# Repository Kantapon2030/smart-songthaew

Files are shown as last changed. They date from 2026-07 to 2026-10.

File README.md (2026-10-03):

# 🚎 SMART SONGTHAEW PLATFORM
### แพลตฟอร์มสมาร์ทสองแถว: สถาปัตยกรรมคลาวด์และไอโอทีติดตามยานพาหนะแบบเรียลไทม์ เพื่อยกระดับคุณภาพชีวิตและลดความเหลื่อมล้ำทางดิจิทัลด้านการเดินทางของประชาชนในส่วนภูมิภาค


[]()
[]()
[]()
[]()
[]()

> **การแข่งขันพัฒนาโปรแกรมคอมพิวเตอร์แห่งประเทศไทย ครั้งที่ 28 (The 28th National Software Contest: NSC 2026)**  
> **หมวดการแข่งขัน:** โปรแกรมเพื่อการประยุกต์ใช้งานบนเครือข่าย หรือโปรแกรมเพื่อพัฒนาคุณภาพชีวิตและสังคม (หมวด 23)  
> **รหัสโครงการ:** `28P23S00194`  
> **ผู้พัฒนา:** นายกันตภณ วงศ์พรต (นักเรียนชั้นมัธยมศึกษาปีที่ 6)  
> **อาจารย์ที่ปรึกษา:** นายอัศวิน จุลมูล  
> **สถานศึกษา:** โรงเรียนเตรียมอุดมศึกษาภาคใต้ จังหวัดนครศรีธรรมราช  
> **ระบบทดสอบจริง (Live Production):** [https://smart-songthaew.onrender.com](https://smart-songthaew.onrender.com)

---

## 📌 สารบัญ (Table of Contents)

1. [ความเป็นมา ที่มาของปัญหา และแรงบันดาลใจ (Background & Motivation)](#1-ความเป็นมา-ที่มาของปัญหา-และแรงบันดาลใจ-background--motivation)
2. [ปัญหาที่แท้จริงของ 2 ฝ่าย (Two-Sided Pain Points)](#2-ปัญหาที่แท้จริงของ-2-ฝ่าย-two-sided-pain-points)
3. [นวัตกรรมและแนวคิดหลักของโครงการ (Core Innovations & Concepts)](#3-นวัตกรรมและแนวคิดหลักของโครงการ-core-innovations--concepts)
4. [สถาปัตยกรรมระบบโดยรวม (System Architecture)](#4-สถาปัตยกรรมระบบโดยรวม-system-architecture)
5. [การออกแบบฮาร์ดแวร์ VIBE และกล่อง 3D PETG (Hardware & Mechanical Design)](#5-การออกแบบฮาร์ดแวร์-vibe-และกล่อง-3d-petg-hardware--mechanical-design)
6. [ผลการทดสอบระบบและประสิทธิภาพภาคสนาม (Field Test & Validation Results)](#6-ผลการทดสอบระบบและประสิทธิภาพภาคสนาม-field-test--validation-results)
7. [ผลกระทบเชิงเศรษฐกิจ สังคม และความยั่งยืน (Social & Economic Impact)](#7-ผลกระทบเชิงเศรษฐกิจ-สังคม-และความยั่งยืน-social--economic-impact)
8. [คุณสมบัติของซอฟต์แวร์และส่วนติดต่อผู้ใช้ (Software Features)](#8-คุณสมบัติของซอฟต์แวร์และส่วนติดต่อผู้ใช้-software-features)
9. [คู่มือการติดตั้งและทดสอบสำหรับนักพัฒนา (Developer & Deployment Guide)](#9-คู่มือการติดตั้งและทดสอบสำหรับนักพัฒนา-developer--deployment-guide)
10. [ปัญหา อุปสรรค และแนวทางการพัฒนาต่อยอด (Challenges & Future Work)](#10-ปัญหา-อุปสรรค-และแนวทางการพัฒนาต่อยอด-challenges--future-work)
11. [ข้อมูลคณะผู้จัดทำและช่องทางติดต่อ (Credits & Contact Information)](#11-ข้อมูลคณะผู้จัดทำและช่องทางติดต่อ-credits--contact-information)

---

## 1. ความเป็นมา ที่มาของปัญหา และแรงบันดาลใจ (Background & Motivation)

### บริบทความเหลื่อมล้ำของระบบขนส่งสาธารณะไทย
ในเขตกรุงเทพมหานครและเมืองศูนย์กลางเศรษฐกิจขนาดใหญ่ เทคโนโลยีติดตามยานพาหนะสาธารณะแบบดิจิทัล (เช่น รถไฟฟ้า BTS/MRT, รถเมล์ ขสมก. ผ่าน ViaBus) ได้ช่วยให้ประชาชนสามารถตรวจสอบเส้นทาง ตำแหน่งรถแบบเรียลไทม์ และวางแผนการเดินทางในชีวิตประจำวันได้อย่างสะดวกรวดเร็ว

ทว่าใน **พื้นที่ต่างจังหวัดและส่วนภูมิภาค** รถสาธารณะหลักที่หล่อเลี้ยงวิถีชีวิตของผู้คนไม่ใช่รถไฟฟ้าหรือรถเมล์ขนาดใหญ่ แต่คือ **"รถสองแถว"** ซึ่งเป็นระบบขนส่งมวลชนท้องถิ่นที่เชื่อมโยงระหว่างบ้าน โรงเรียน ตลาด สถานที่ทำงาน โรงพยาบาล และศูนย์กลางชุมชนเข้าด้วยกัน อย่างไรก็ดี รถสองแถวในปัจจุบันยังคงเป็นระบบขนส่งแบบดั้งเดิม (Analog) ที่ **"ผู้โดยสารมองไม่เห็น"** ไม่มีระบบดิจิทัลบอกตำแหน่ง ไม่ทราบตารางเวลาที่แน่นอน และไม่มีช่องทางตรวจสอบว่ารถคันถัดไปจะมาถึงเมื่อใด

### ความสอดคล้องกับนโยบายระดับประเทศและสากล
- **ข้อเสนอเชิงนโยบาย TDRI:** สถาบันวิจัยเพื่อการพัฒนาประเทศไทย (TDRI) ระบุว่า แกนหลักของปัญหาการขนส่งสาธารณะไทยผูกอยู่กับ 3 มิติคือ **"เวลา ความแน่นอน และการเข้าถึงพื้นที่ปลายทาง"** พร้อมเสนอว่ารถโดยสารสาธารณะที่ได้รับการยกระดับควรติดตั้งระบบ GPS และเชื่อมต่อแอปพลิเคชันให้ผู้โดยสารตรวจสอบตำแหน่งได้จริง
- **เป้าหมายการพัฒนาที่ยั่งยืน (UN SDG 11.2):** โครงการนี้มุ่งสนับสนุนเป้าหมาย SDG 11 (Sustainable Cities and Communities) ข้อ 11.2 ว่าด้วยการจัดให้ทุกคนสามารถเข้าถึงระบบคมนาคมขนส่งที่ปลอดภัย ราคาย่อมเยา เข้าถึงได้สะดวก และยั่งยืน เพื่อลดความเหลื่อมล้ำทางดิจิทัล (Digital Divide) ด้านการเดินทางของประชาชนในส่วนภูมิภาค

---

## 2. ปัญหาที่แท้จริงของ 2 ฝ่าย (Two-Sided Pain Points)

จากการลงพื้นที่สำรวจและวิเคราะห์บริบทจริงในจังหวัดนครศรีธรรมราช พบว่าอุปสรรคสำคัญที่ทำให้ระบบติดตามรถไม่เคยเกิดขึ้นสำเร็จในรถสองแถวท้องถิ่น เกิดจากความไม่สอดคล้องของปัญหาและความต้องการระหว่างสองฝ่าย:

```
┌───────────────────────────────────────────────┐     ┌───────────────────────────────────────────────┐
│              ฝั่งผู้โดยสาร (Passenger)           │     │       ฝั่งผู้ประกอบการสองแถว (Operator)       │
├───────────────────────────────────────────────┤     ├───────────────────────────────────────────────┤
│ ❌ ไม่ทราบตำแหน่งรถและเวลาที่รถจะมาถึง (ETA)   │     │ ❌ อุปกรณ์ GPS เชิงพาณิชย์ราคาแพงมาก          │
│ ❌ เวลารอรถไม่แน่นอน เสียเวลา/เสียโอกาสชีวิต   │     │    (3,000 – 5,000 บาท / กล่อง)               │
│ ❌ ข้อมูลการเดินรถไม่ชัดเจน                    │     │ ❌ ภาระค่าซิม 4G รายเดือนสูงเกินไป            │
│ ❌ เสี่ยงอันตรายในการยืนรอริมถนนเปลี่ยว         │     │    (300 – 500 บาท / คัน / เดือน)             │
│    (โดยเฉพาะนักเรียน ผู้หญิง และผู้สูงอายุ)   │     │ ❌ ติดตั้งยุ่งยาก ต้องตัดต่อดัดแปลงระบบไฟรถ   │
└───────────────────────────────────────────────┘     └───────────────────────────────────────────────┘
                                        ▼                                     ▼
                        ┌─────────────────────────────────────────────────────────────┐
                        │                 SMART SONGTHAEW PLATFORM                    │
                        │   ติดตามรถสองแถวเรียลไทม์ ผ่าน LoRa Mesh + Web App ไม่โหลดแอป  │
                        │        ต้นทุนฮาร์ดแวร์ต่ำ • ไม่ต้องจ่ายค่าซิมเน็ตทุกคัน • เสียบใช้ได้ทันที    │
                        └─────────────────────────────────────────────────────────────┘
```

1. **ฝั่งผู้โดยสาร (Passengers & Students):**
   - **ความไม่แน่นอนของเวลา:** ต้องยืนรอรถโดยไม่รู้ว่าจะมาเมื่อไหร่ ทำให้เสียเวลาเรียน เสียงาน หรือพลาดนัดหมายสำคัญ
   - **ความปลอดภัยในชีวิต:** ในพื้นที่ชนบท ป้ายรอรถมักเป็นศาลาริมทางหรือริมถนนสายรองที่ไม่มีไฟส่องสว่างเพียงพอ การยืนรอรถเป็นเวลานานในยามค่ำคืนหรือช่วงฝนตกก่อให้เกิดความเสี่ยงต่อความปลอดภัย
   - **อุปสรรคในการเข้าถึงแอป:** ผู้สูงอายุและผู้ใช้ทั่วไปมักมีโทรศัพท์มือถือที่มีหน่วยความจำจำกัด การบังคับให้โหลดแอปพลิเคชันเฉพาะทางทำให้คนส่วนใหญ่เลือกที่จะไม่ใช้งาน

2. **ฝั่งผู้ประกอบการและคนขับรถสองแถว (Operators & Drivers):**
   - **ต้นทุนอุปกรณ์สูง:** กล่อง GPS Tracker เชิงพาณิชย์ในท้องตลาดมีราคา 3,000 – 5,000 บาท ซึ่งไม่คุ้มค่าทางเศรษฐกิจสำหรับคนขับรถรับจ้างรายย่อย
   - **ภาระค่าบริการรายเดือน (Recurring Cellular Cost):** การที่ต้องใส่ซิม 4G/LTE ทุกคัน คิดเป็นต้นทุนคันละ 300 – 500 บาท/เดือน (ปีละ 3,600 – 6,000 บาท/คัน) กลายเป็นอุปสรรคใหญ่ที่สุดที่ทำให้ระบบไม่ยั่งยืน
   - **ความยุ่งยากในการติดตั้ง (Retrofit Barrier):** ระบบทั่วไปต้องช่างเทคนิคตัดต่อสายไฟเมนของตัวรถ เสี่ยงต่อการลัดวงจร ไฟไหม้ หรือประกันรถยนต์ขาด

---

## 3. นวัตกรรมและแนวคิดหลักของโครงการ (Core Innovations & Concepts)

แพลตฟอร์ม Smart Songthaew ได้รับการออกแบบขึ้นมาใหม่ทั้งหมดเพื่อแก้ Pain Points ข้างต้นอย่างตรงจุด ผ่าน 5 นวัตกรรมหลัก:

### 3.1 นวัตกรรมระบบสื่อสาร VIBE (Vehicle Information Broadcast Exchange)
ได้รับแรงบันดาลใจจากเทคโนโลยี **ADS-B (Automatic Dependent Surveillance-Broadcast)** ที่ใช้ในอุตสาหกรรมการบินสากล โดยเครื่องบินจะส่งสัญญาณระบุพิกัด ความเร็ว และทิศทางของตนเองออกไปในอากาศแบบสาธารณะ  
โครงการนี้นำหลักการดังกล่าวมาประยุกต์ใช้กับ **รถสองแถวท้องถิ่น** โดยให้รถสองแถวแต่ละคันส่งกระจายแพ็กเก็ตข้อมูลระบุตัวตน (Vehicle ID), พิกัด GPS, ความเร็ว, ทิศทาง และสถานะพลังงาน ผ่านคลื่นวิทยุพลังงานต่ำ Sub-GHz เพื่อให้รถคันอื่นและสถานีฐานในพื้นที่รับรู้ได้ทันที

### 3.2 เครือข่าย LoRa Multi-hop Mesh Networking (หัวใจของระบบ)
- **ไม่จำเป็นต้องมีซิม 4G ในรถทุกคัน:** รถสองแถวใช้โมดูลวิทยุ LoRa ย่านความถี่สาธารณะของประเทศไทย (AS923 / 923 MHz) ในการสื่อสาร
- **Vehicle-to-Vehicle (V2V) & Vehicle-to-Infrastructure (V2I):** รถที่อยู่นอกระยะสัญญาณของสถานีฐาน สามารถส่งข้อมูล "กระโดดข้าม" (Hop Relay สูงสุด 2–3 ทอด) ผ่านรถสองแถวคันข้างหน้าเพื่อส่งต่อไปยังสถานีฐาน (Ground Station)
- **ต้นทุนค่าอินเทอร์เน็ตลดลงเหลือจุดเดียว:** มีเพียงสถานีฐาน (Ground Station) ประจำจุดตรวจหรือจุดจอดหลักเท่านั้นที่เชื่อมต่อ Wi-Fi หรือ Cellular Gateway เพื่อส่งข้อมูลขึ้น Cloud ทำให้ประหยัดค่าซิมการ์ดให้กับฝูงรถทั้งเส้นทาง

```
[ รถคันที่ 3 (BUS_03) ] ──(Hop 2)──► [ รถคันที่ 2 (BUS_02) ] ──(Hop 1)──► [ รถคันที่ 1 (BUS_01) ] ──(Hop 0)──► [ สถานีฐาน (GROUND_01) ] ──(Internet)──► [ CLOUD & WEB ]
  (อยู่นอกระยะสถานี)                     (ทำหน้าที่ Relay)                     (ใกล้สถานีที่สุด)
```

### 3.3 ระบบบัฟเฟอร์ข้อมูลออฟไลน์ Store-and-Forward
ในภูมิประเทศจริงที่มีหุบเขา อาคารสูง หรือป่าทึบบดบังสัญญาณวิทยุ (Dead Zone) อุปกรณ์ VIBE บนตัวรถจะมีระบบ **Offline Ring-Buffer Caching** ทำการบันทึกประวัติพิกัดและลำดับแพ็กเก็ต (Sequence & Hash) ไว้ในหน่วยความจำชั่วคราว และเมื่อรถวิ่งกลับเข้ามาในรัศมีเครือข่าย VIBE ระบบจะทำการ "Flush & Forward" ส่งข้อมูลย้อนหลังกลับเข้าสถานีฐานโดยอัตโนมัติ ป้องกันข้อมูลตำแหน่งสูญหาย

### 3.4 เครื่องคำนวณและคาดการณ์เวลา VIBE Predict (AI & Estimation Engine)
ระบบหลังบ้านประกอบด้วยเครื่องมือประมวลผลตำแหน่งอัจฉริยะ 3 ขั้นตอน:
1. **Map Matching:** จับพิกัดละติจูด/ลองจิจูดจาก GPS ให้เข้าสู่แนวแกนถนนจริง (Snapped to Route Geometry) ลดข้อผิดพลาดจากสัญญาณสะท้อน (Multipath) และ GPS Drift
2. **Kalman Filter:** คาดคะเนตำแหน่งและความเร็วอย่างราบรื่น (Smooth Motion) แม้ในช่วงเวลาที่สัญญาณขาดหายชั่วคราว
3. **Route Profile & Traffic-Aware ETA:** เรียนรู้ความเร็วเฉลี่ยตามสภาพถนนและช่วงเวลา คำนวณเวลาที่รถจะมาถึงป้ายปลายทาง พร้อมระบุระดับความเชื่อมั่น (Confidence Score)

### 3.5 ประสบการณ์ผู้โดยสารแบบไร้รอยต่อ (Zero-Barrier Web Experience)
ผู้โดยสารสามารถเปิดดูตำแหน่งรถสองแถวแบบเรียลไทม์ได้ทันทีผ่าน Web Browser (Chrome, Safari, Edge) ทั้งบนมือถือ แท็บเล็ต และคอมพิวเตอร์ **โดยไม่ต้องดาวน์โหลดหรือติดตั้งแอปพลิเคชันใดๆ** เพียงแค่สแกน QR Code ที่ป้ายรถสองแถวหรือคลิกลิงก์ระบบ

---

## 4. สถาปัตยกรรมระบบโดยรวม (System Architecture)

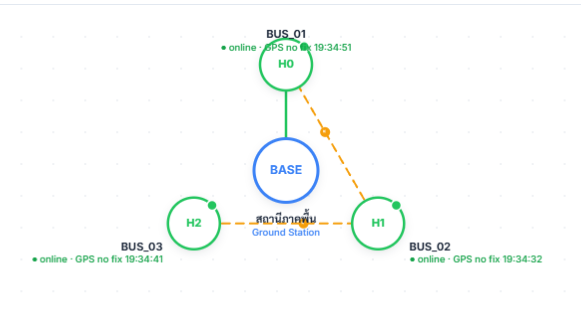
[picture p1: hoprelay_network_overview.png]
ภาพรวมโครงข่าย VIBE Mesh และระบบรับส่งข้อมูล


ระบบแบ่งออกเป็น 4 ชั้นการทำงานหลัก (Layer Architecture):

```mermaid
flowchart TD
    subgraph S1["1. ยานพาหนะ (Vehicle Node - VIBE)"]
        GPS["NEO-6M GPS"] -->|พิกัด/ความเร็ว| MCU["ESP8266 NodeMCU"]
        BAT["Battery 18650 & Solar"] -->|แรงดันไฟฟ้า A0| MCU
        MCU -->|แพ็กเก็ต VIBE Protocol| LORA_TX["SX1276 LoRa 923MHz"]
    end

    subgraph S2["2. เครือข่าย VIBE Mesh (Sub-GHz)"]
        LORA_TX -.->|V2V Relay (Hop 1-2)| RELAY["รถคันกลาง (Relay Node)"]
        RELAY -.->|LoRa Packet| GROUND["สถานีฐาน Ground Station"]
        LORA_TX ==>|Direct Link (Hop 0)| GROUND
    end

    subgraph S3["3. คลาวด์และระบบประมวลผลกลาง (Cloud Backend)"]
        GROUND -->|HTTP POST Telemetry Batch| API["Express 5 REST API (Render)"]
        API -->|ตรวจสอบสิทธิ์ X-Vehicle-Key / Hashing| SEC["Security & Rate Limiting"]
        SEC -->|อัปเดตตำแหน่งสด| RTDB["Firebase Realtime Database"]
        SEC -->|Traffic ETA Calculation| GMAPS["Google Maps / Routes API"]
    end

    subgraph S4["4. ส่วนติดต่อผู้ใช้งาน (Client Interfaces)"]
        RTDB -->|Realtime WebSocket Sync| PASSENGER["เว็บผู้โดยสาร (Mobile-first Web App)"]
        RTDB -->|Live Diagnostics| DASHBOARD["หน้าต่างมอนิเตอร์โครงข่าย (Mesh Dashboard)"]
        RTDB -->|Fleet Management| ADMIN["ระบบจัดการผู้ดูแล (Admin Operations Console)"]
    end
```

### การเปรียบเทียบระบบติดตามรถทั่วไป vs Smart Songthaew VIBE

| มิติเปรียบเทียบ | ระบบ GPS Tracker ทั่วไปในท้องตลาด | ระบบ Smart Songthaew (VIBE Mesh) |
|---|---|---|
| **ค่าซิมการ์ดประจำเดือน** | 300 – 500 บาท / คัน / เดือน ทุกคัน | **0 บาท สำหรับรถทุกคัน** (ต่อเน็ตเฉพาะสถานีฐาน) |
| **ต้นทุนค่าฮาร์ดแวร์** | 3,000 – 5,000 บาท / กล่อง | **ไม่เกิน 1,200 – 1,500 บาท** (Open-Hardware ต้นทุนต่ำ) |
| **การติดตั้งบนตัวรถ** | ต้องตัดต่อระบบไฟรถ เสี่ยงไฟฟ้าลัดวงจร | **Retrofit Plug & Play** เสียบไฟ USB/แบตเตอรี่ในตัวได้ทันที |
| **การใช้งานของผู้โดยสาร** | ต้องดาวน์โหลดและติดตั้งแอปพลิเคชัน | **เปิดผ่านเว็บเบราว์เซอร์ได้ทันที** สแกน QR Code แล้วดูได้เลย |
| **การทำงานในจุดอับสัญญาณ** | ข้อมูลขาดหายเมื่อไม่มีสัญญาณ 4G | **LoRa ยิงทะลุสิ่งกีดขวาง + Store-and-Forward + Hop Relay** |
| **การประหยัดพลังงาน** | กินไฟสูง 1–3 วัตต์ตลอดเวลา | **พลังงานต่ำ (Low-Power TDMA Slot)** ใช้งานได้ต่อเนื่องเกิน 24 ชม. |

---

## 5. การออกแบบฮาร์ดแวร์ VIBE และกล่อง 3D PETG (Hardware & Mechanical Design)

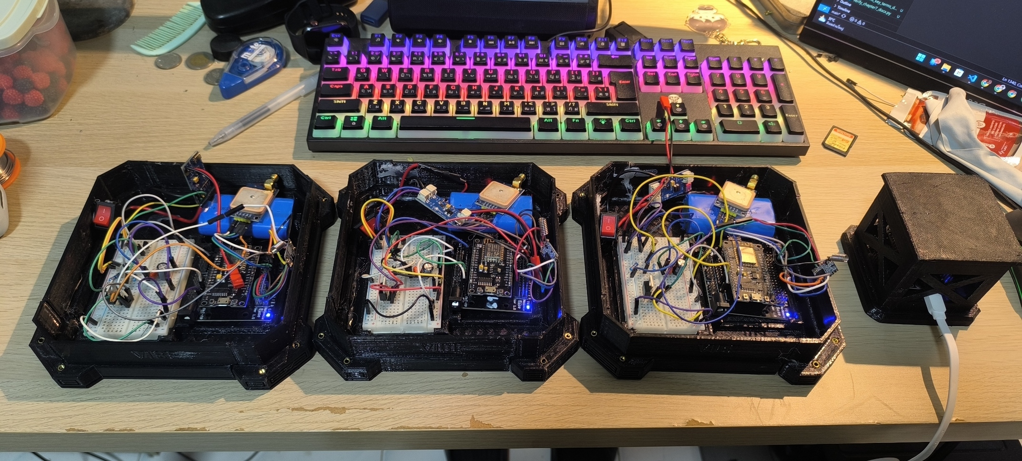
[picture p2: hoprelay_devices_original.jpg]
อุปกรณ์ VIBE ต้นแบบและส่วนประกอบหลัก


### 5.1 รายการอุปกรณ์และสเปกเชิงวิศวกรรม (Bill of Materials)

| อุปกรณ์ | หน้าที่และสเปกเชิงเทคนิค |
|---|---|
| **MCU Board** | **ESP8266 NodeMCU (ESP-12F):** หน่วยประมวลผล 32-bit 80/160 MHz ควบคุมเวลา TDMA, จัดสรรบัฟเฟอร์, คำนวณ CRC/Hash |
| **GPS Module** | **u-blox NEO-6M:** โมดูลรับสัญญาณพิกัด GPS/GNSS อัตรา 9600 baud พร้อมเสาอากาศ Active Ceramic Patch 25x25 มม. |
| **LoRa Module** | **Semtech SX1276 (Ra-02):** ความถี่ 923 MHz (AS923 TH Band), กำลังส่ง 17 dBm (50 mW), SF7, BW 125 kHz, CR 4/5 |
| **Power Storage** | **Li-ion 18650 Battery (3.7V 2600–4400 mAh):** แหล่งพลังงานอิสระ ไม่ดึงไฟจากระบบรถ |
| **Battery Management** | **TP4056 + วงจรตรวจวัดแรงดัน A0:** ควบคุมการชาร์จแบตเตอรี่ พร้อมวงจรแบ่งแรงดัน (Voltage Divider) มอนิเตอร์ % แบตเตอรี่ |
| **Solar Auxiliary** | **แผงโซลาร์เซลล์ 5V 1–2W (Optional):** เสริมการประจุไฟในเวลากลางวัน ยืดอายุการใช้งานภาคสนาม |
| **Switching Circuit** | **P-Channel MOSFET (IRF9540N):** ควบคุมการเปิด-ปิดระบบพลังงานอัตโนมัติ |
| **Enclosure Case** | **PETG 3D Printed Case:** กล่องเคสออกแบบเฉพาะ พิมพ์ด้วยเส้นใย **PETG 100% Infill/Perimeter** ทนความร้อนและแสงแดดจัด |

### 5.2 การออกแบบโครงสร้างทางกลและวัสดุเคส (PETG 3D Printing Enclosure)
- **ทำไมต้องเป็น PETG (Polyethylene Terephthalate Glycol):** การใช้งานบนรถสองแถวในภาคใต้ของไทยต้องเผชิญกับอุณหภูมิกลางแดดที่สูงเกิน 40–50°C ภายในห้องโดยสารและหลังคารถ หากใช้วัสดุทั่วไปอย่าง PLA ชิ้นงานจะอ่อนตัวและเสียรูป (Glass Transition Temp ~60°C) วัสดุ PETG มีคุณสมบัติทนความร้อนสูง ทนทานต่อรังสี UV และมีความเหนียว (High Impact Resistance) ไม่แตกหักง่ายเมื่อเกิดแรงสั่นสะเทือนขณะรถวิ่ง
- **การจัดวางภายใน (Internal Layout):** แยกเสาอากาศ LoRa และโมดูล GPS ออกจากแผงวงจรชาร์จไฟ เพื่อป้องกันคลื่นแม่เหล็กไฟฟ้ารบกวน (EMI) พร้อมช่องระบายความร้อนเพื่อยืดอายุการใช้งานของแบตเตอรี่

---

## 6. ผลการทดสอบระบบและประสิทธิภาพภาคสนาม (Field Test & Validation Results)

การทดสอบระบบ Smart Songthaew ดำเนินการจริงบนเส้นทางรถสองแถวสาย **นครศรีธรรมราช – พรหมคีรี (NST-PROMKHIRI)** และพื้นที่ทดสอบภาคสนาม โดยสรุปผลตามมิติต่างๆ ดังนี้:

### 6.1 การทดสอบคุณภาพสัญญาณ LoRa ตามระยะทาง (RSSI & SNR vs Distance)

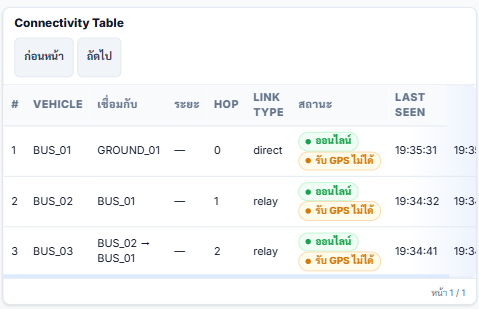
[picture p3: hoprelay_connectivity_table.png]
ตารางการเชื่อมต่อและสถานะเครือข่าย Hop Relay


จากการทดสอบส่งข้อมูลระหว่างโหนดยานพาหนะและสถานีฐานในพื้นที่จริง:
- **ระยะ 0 – 50 เมตร:** RSSI เฉลี่ย **-72.4 dBm**, SNR **+8.5 dB** (คุณภาพสัญญาณดีเยี่ยม ความเร็วส่งสมบูรณ์ 100%)
- **ระยะ 100 – 150 เมตร:** RSSI เฉลี่ย **-84.1 dBm**, SNR **+4.2 dB** (การรับส่งข้อมูลเสถียร ไม่พบแพ็กเก็ตตกหล่น)
- **ระยะ 324 เมตร (Hop 0 ในพื้นที่เปิดโล่ง):** RSSI **-105.0 dBm**, SNR **-6.25 dB** (สามารถถอดรหัสแพ็กเก็ตพิกัดได้ถูกต้องครบถ้วน)
- **ระยะเกิน 500 เมตร (มีสิ่งกีดขวาง):** ระบบเริ่มเปลี่ยนผ่านเข้าสู่โหมด **Multi-hop Relay** โดยอัตโนมัติ

### 6.2 การทดสอบการส่งต่อข้อมูลหลายทอด (Multi-hop Forced Relay Validation)
ในการทดสอบแบบบังคับทอด (Forced-hop Test) ตามเส้นทาง:
$$\text{BUS\_03} \xrightarrow{\text{Hop 2}} \text{BUS\_02} \xrightarrow{\text{Hop 1}} \text{BUS\_01} \xrightarrow{\text{Hop 0}} \text{GROUND\_01}$$
- ดำเนินการทดสอบต่อเนื่อง **30 รอบวัฏจักร (30 Cycles)**
- สถานีฐานสามารถรับแพ็กเก็ตสุดท้ายที่ผ่านการ Relay ได้สำเร็จ **29 จาก 30 รอบ (ความสำเร็จ 96.67%)**
- ความหน่วงรวมเฉลี่ยของการกระโดด 2 ทอด (Relay Latency) อยู่ที่ประมาณ **1.2 – 1.8 วินาที** ซึ่งเพียงพออย่างยิ่งสำหรับระบบติดตามยานพาหนะแบบเรียลไทม์

### 6.3 การทดสอบระยะเวลาการหาพิกัด GPS (Time-To-First-Fix: TTFF)
- **Cold Start (เปิดเครื่องครั้งแรกในพื้นที่โล่ง):** ใช้เวลาเฉลี่ย **27.8 วินาที** ในการล็อกพิกัดดาวเทียม
- **Warm / Hot Start (ปิด-เปิดใหม่ หรือหลุดจากอุโมงค์/ร่มไม้):** ใช้เวลาเพียง **1.5 – 3.2 วินาที** เนื่องจากระบบมีการบันทึกตำแหน่งล่าสุด (Last-known-fix) ลง EEPROM

### 6.4 การประเมินพลังงานและระยะเวลาใช้งานของแบตเตอรี่ (Power & Battery Runtime)
- **อัตราการใช้กระแสไฟฟ้าเฉลี่ย:**
  - ขณะสแตนด์บายรับฟัง (Rx Window): **~38 mA**
  - ขณะอ่านค่า GPS ต่อเนื่อง: **~55 mA**
  - ขณะส่งสัญญาณ LoRa Tx (17 dBm, ระยะเวลาส่ง ~60 ms): **~130 mA**
  - กระแสเฉลี่ยตลอดทั้งวัฏจักรการทำงาน (Duty Cycle 5 วินาที): **~45 – 52 mA**
- **ผลการทดสอบแบตเตอรี่ Li-ion 18650 (3.7V 2600 mAh):**
  - สามารถทำงานต่อเนื่องได้มากกว่า **27.25 ชั่วโมง** ต่อการชาร์จเต็ม 1 ครั้ง
  - ครอบคลุมชั่วโมงการเดินรถจริงของรถสองแถวประจำวัน (06:00 – 18:00 น. = 12 ชั่วโมง) ได้อย่างปลอดภัยและมีพลังงานสำรองเหลือเกิน 50%

---

## 7. ผลกระทบเชิงเศรษฐกิจ สังคม และความยั่งยืน (Social & Economic Impact)

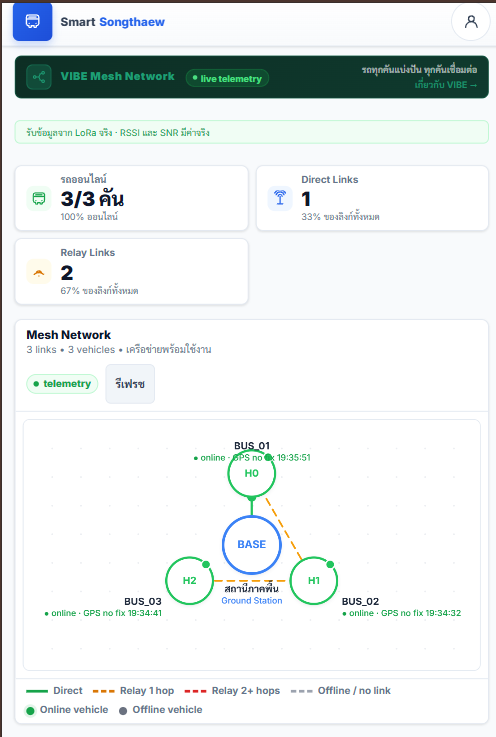
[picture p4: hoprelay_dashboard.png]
แดชบอร์ดติดตามเครือข่าย VIBE Hop Relay


| กลุ่มผู้มีส่วนได้ส่วนเสีย | ประโยชน์ที่ได้รับจากแพลตฟอร์ม Smart Songthaew |
|---|---|
| **นักเรียน นักศึกษา และเยาวชน** | สามารถวางแผนออกจากบ้านหรือห้องเรียนได้ตรงเวลา ไม่ต้องเสียเวลายืนรอรถนานกว่า 20–40 นาที ลดความเสี่ยงในการไปเรียนสาย |
| **ประชาชนและผู้สูงอายุ** | ไม่ต้องยืนตากแดดหรือตากฝนริมถนนเปลี่ยว สามารถรอรถในที่ปลอดภัยจนกว่ารถจะใกล้ถึงจุดรับส่ง เสริมสร้างสุขภาวะและความปลอดภัย |
| **คนขับรถและผู้ประกอบการสองแถว** | ประหยัดต้นทุนค่าซิมอินเทอร์เน็ตได้ปีละ **3,600 – 6,000 บาทต่อคัน** มีอุปกรณ์ติดรถที่ทนทาน ไม่รบกวนระบบไฟรถยนต์ และเพิ่มโอกาสให้ผู้โดยสารเลือกใช้บริการรถสองแถวมากขึ้น |
| **ชุมชน เทศบาล และ อปท.** | สามารถนำสถิติการเดินรถจริง (Fleet Telemetry Data) มาวิเคราะห์ความหนาแน่น วางแผนป้ายจอดรถ และปรับปรุงการจัดสรรเส้นทางขนส่งสาธารณะได้อย่างมีประสิทธิภาพ |

---

## 8. คุณสมบัติของซอฟต์แวร์และส่วนติดต่อผู้ใช้ (Software Features)

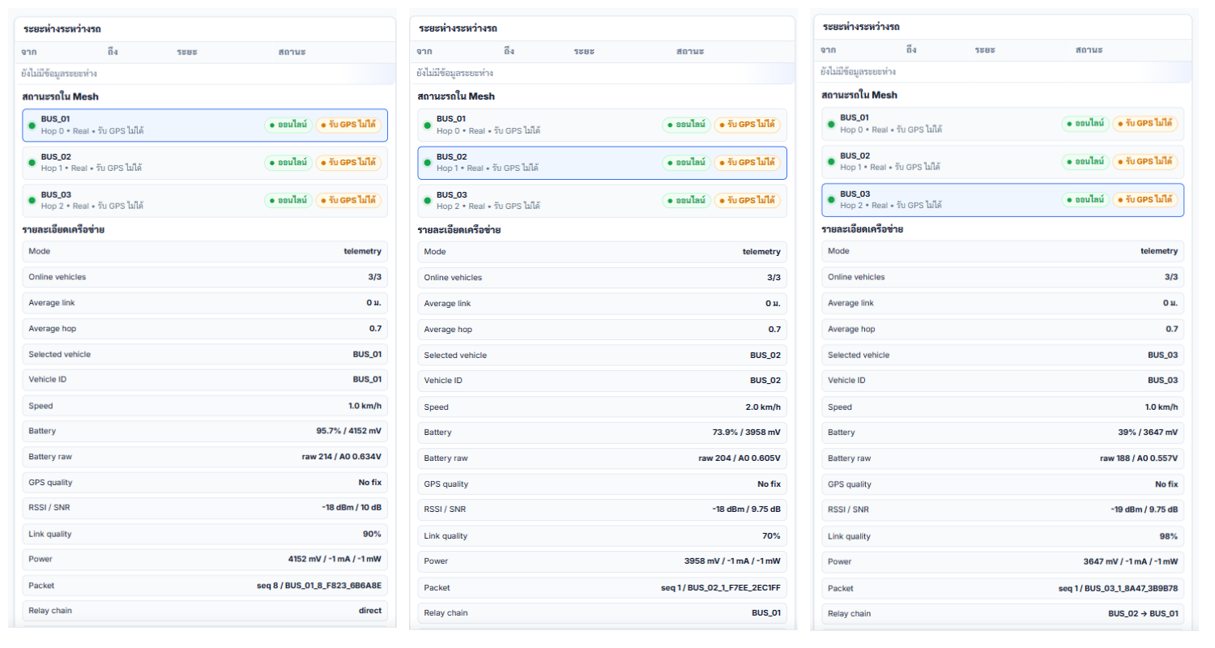
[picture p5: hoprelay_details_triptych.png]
รายละเอียดสถานะของรถแต่ละคันในโครงข่าย


1. **เว็บแอปพลิเคชันสำหรับผู้โดยสาร (`/index.html`):**
   - แผนที่แสดงตำแหน่งรถสองแถวเคลื่อนที่แบบเรียลไทม์ (Smooth Interpolation)
   - การแสดงสถานะรถ: ความเร็ว, ระดับแบตเตอรี่, เวลาที่อัปเดตล่าสุด (Live / Delayed / Offline)
   - การสลับเส้นทางและทิศทางเดินรถ (เที่ยวไป Outbound / เที่ยวกลับ Inbound)
   - ระบบค้นหาและเลือกป้ายหยุดรถสำคัญ เพื่อประเมินเวลาที่รถจะมาถึง (ETA)
   - รองรับการใช้งานสมาร์ตโฟน 100% (Mobile Responsive, PWA-ready)

2. **ระบบมอนิเตอร์โครงข่าย VIBE (`/dashboard.html`):**
   - แผนภาพกราฟความสัมพันธ์ของโหนด (Network Topology Graph)
   - แสดงสถานะ Hop Count, คุณภาพสัญญาณ RSSI/SNR ของแต่ละลิงก์
   - อัปเดตข้อมูลอัตโนมัติผ่าน Realtime Database ทุก 5–10 วินาที

3. **คอนโซลบริหารจัดการและรักษาความปลอดภัย (`/operations.html` & `/admin.html`):**
   - ระบบยืนยันตัวตนแอดมินด้วย HTTP-only Cookie และ JWT
   - การลงทะเบียนและจัดการกุญแจรถ (Vehicle Key Provisioning) ด้วยระบบ Salted Hash
   - การจัดการเส้นทาง พิกัดแนวถนน (Waypoints) และป้ายหยุดรถ (Stops)

4. **เครื่องมือตรวจวินิจฉัยภาคสนาม (`/fieldtest.html` & `/history.html`):**
   - บันทึกประวัติ Log การส่งข้อมูลแบบละเอียด (Packet Sequence, Hash, Relay Route)
   - กราฟวิเคราะห์ระดับแรงดันแบตเตอรี่และการเสื่อมของสัญญาณตามระยะทาง
   - ส่งออกข้อมูลการทดสอบเป็นไฟล์ CSV เพื่อการวิเคราะห์ทางสถิติ

---

## 9. คู่มือการติดตั้งและทดสอบสำหรับนักพัฒนา (Developer & Deployment Guide)

### 9.1 ความต้องการพื้นฐานของระบบ (Prerequisites)
- **Node.js:** เวอร์ชั่น 18.0.0 ขึ้นไป
- **npm:** เวอร์ชั่น 9.0.0 ขึ้นไป
- **Arduino IDE:** เวอร์ชั่น 2.x (พร้อมติดตั้ง ESP8266 Core และ Library: `LoRa`, `ArduinoJson`, `TinyGPSPlus`)
- บัญชี **Firebase Realtime Database** และ **Google Maps Platform API Key**

### 9.2 การติดตั้งและรัน Web Server ในเครื่อง (Local Setup)

```bash
# 1. เข้าสู่โฟลเดอร์โปรเจกต์
cd smart-songthaew

# 2. ทำการคัดลอกไฟล์ Environment Variables
cp .env.example .env

# 3. ติดตั้ง Dependencies ทั้งหมด
npm install

# 4. ทดสอบความถูกต้องของโปรแกรมด้วย Automated Test Suite (27 ชุดทดสอบ)
npm test

# 5. รันเซิร์ฟเวอร์สำหรับสภาพแวดล้อม Development
npm run dev
```

เปิดเว็บเบราว์เซอร์แล้วเข้าสู่:
- **หน้าผู้โดยสาร (Passenger Map):** `http://localhost:3000/`
- **แดชบอร์ดเครือข่าย (VIBE Dashboard):** `http://localhost:3000/dashboard.html`
- **หน้าจัดการระบบ (Admin Operations):** `http://localhost:3000/operations.html`

### 9.3 การตั้งค่าสิ่งแวดล้อม (.env Configuration)

```env
PORT=3000
JWT_SECRET=your-secure-jwt-secret-key-min-32-chars
ADMIN_USERNAME=admin
ADMIN_PASSWORD_HASH=$2a$10$YourHashedBcryptPasswordHere

# Firebase Configuration
FIREBASE_DATABASE_URL=https://your-project-default-rtdb.firebaseio.com
FIREBASE_SERVICE_ACCOUNT_KEY={"type":"service_account",...}

# Google Maps API Keys
GOOGLE_MAPS_API_KEY=AIzaSyYourGoogleMapsKey
GOOGLE_ROUTES_API_KEY=AIzaSyYourRoutesKey
```

### 9.4 การแฟลชเฟิร์มแวร์ฮาร์ดแวร์ (Firmware Flashing)
1. **ฝั่งอุปกรณ์บนรถสองแถว:**
   - เปิดไฟล์ `Songthaew_V03_vehicle.ino` ใน Arduino IDE
   - ตั้งค่าบอร์ดเป็น `NodeMCU 1.0 (ESP-12E Module)`
   - สร้างไฟล์ `songthaew_secrets.h` จากตัวอย่าง `songthaew_secrets.example.h` และระบุ `VEHICLE_ID` (เช่น `BUS_01`)
   - แฟลชโปรแกรมลงบอร์ดผ่านพอร์ต USB
2. **ฝั่งสถานีฐาน (Ground Station):**
   - เปิดไฟล์ `Songthaew_V03_ground.ino`
   - ใส่ชื่อ Wi-Fi SSID, รหัสผ่าน และ URL ของ Cloud Server ใน `songthaew_secrets.h`
   - แฟลชโปรแกรมลงบอร์ด และติดตั้งในตำแหน่งที่รับสัญญาณ LoRa ได้ชัดเจน

### 9.5 การทดสอบ Forced-hop Relay ในระดับเฟิร์มแวร์
ในการทดสอบการทรานสปอร์ตข้อมูล 2 ทอด สามารถเปิดโหมดทดสอบใน `mesh_config.h`:

```cpp
#define FORCED_HOP_TEST_ENABLED       1
#define FORCED_HOP_TEST_SOURCE        "BUS_03"
#define FORCED_HOP_TEST_RELAY_1       "BUS_02"
#define FORCED_HOP_TEST_RELAY_2       "BUS_01"
```

---

## 10. ปัญหา อุปสรรค และแนวทางการพัฒนาต่อยอด (Challenges & Future Work)

### ปัญหาและอุปสรรคที่พบจากการทดสอบจริง
1. **การประกอบวงจรบน Breadboard:** ในระยะต้นแบบบางส่วนยังประกอบบน Breadboard เมื่อติดตั้งบนรถสองแถวจริงที่มีแรงสั่นสะเทือนต่อเนื่อง อาจเสี่ยงต่อปัญหาสาย Jumper หลวมหลุด
2. **ความร้อนสะสมกลางแดดจัด:** สภาพภูมิอากาศภาคใต้ที่มีแดดจัดในตอนกลางวัน ทำให้อุณหภูมิภายในกล่องอุปกรณ์สูงขึ้น แม้เคส PETG จะไม่ละลาย แต่ส่งผลต่อประสิทธิภาพของแบตเตอรี่ Li-ion
3. **จุดอับสัญญาณดาวเทียม (GPS Multipath):** การขับรถผ่านบริเวณอาคารพาณิชย์หนาแน่นหรือใต้แนวต้นไม้ใหญ่ ทำให้สัญญาณ GPS คลาดเคลื่อนชั่วขณะ

### แนวทางการพัฒนาในระยะถัดไป (Roadmap)
- [ ] **การผลิตแผ่นวงจรพิมพ์เฉพาะ (Custom PCB Shield):** ออกแบบ Custom PCB เพื่อลดขนาดอุปกรณ์ ขจัดปัญหาสายหลวม และเพิ่มความทนทานต่อแรงกระแทก
- [ ] **การปรับปรุงกล่องระบายความร้อน (Enhanced Aerated Case):** ออกแบบเคส PETG รุ่นใหม่ที่มีช่องระบายความร้อนแบบกันน้ำสาด (IP54 Enclosure with Ventilation Baffle)
- [ ] **ระบบแจ้งเตือนผู้โดยสารอัจฉริยะ (Proximity Alert):** เพิ่มระบบแจ้งเตือนผ่าน LINE Notify หรือ Web Notification เมื่อรถสองแถวอยู่ห่างจากป้ายของผู้โดยสารในระยะ 500 เมตร
- [ ] **การขยายผลสู่ยานพาหนะประเภทอื่น:** ขยายสถาปัตยกรรม VIBE ไปใช้กับรถรับส่งนักเรียนประจำอำเภอ, รถบริการการแพทย์ฉุกเฉินชุมชน, และรถขนส่งผลผลิตทางการเกษตร

---

## 11. ข้อมูลคณะผู้จัดทำและช่องทางติดต่อ (Credits & Contact Information)

โครงการนี้ได้รับการพัฒนาขึ้นภายใต้การประกวดโครงงานของเยาวชนไทย **National Software Contest 2026 (NSC 2026)** ด้วยความตั้งใจที่จะนำความรู้ด้านวิทยาการคอมพิวเตอร์และวิศวกรรมไอโอทีมาแก้ปัญหาความเหลื่อมล้ำในการดำรงชีวิตของประชาชนในท้องถิ่นบ้านเกิด

### คณะผู้จัดทำ
- **ผู้พัฒนาโครงงาน:**  
  **นายกันตภณ วงศ์พรต (Mr. Kantapon Wongprot)**  
  นักเรียนระดับชั้นมัธยมศึกษาปีที่ 6 โรงเรียนเตรียมอุดมศึกษาภาคใต้  
  📞 โทรศัพท์: `083-813-0442`  
  📧 อีเมล: `11153@triamudomsouth.ac.th` / `tawna20081@gmail.com`  
  🐙 GitHub: [@Kantapon2030](https://github.com/Kantapon2030)

- **อาจารย์ที่ปรึกษาโครงงาน:**  
  **นายอัศวิน จุลมูล (Mr. Assawin Chulmool)**  
  กลุ่มสาระการเรียนรู้วิทยาศาสตร์และเทคโนโลยี โรงเรียนเตรียมอุดมศึกษาภาคใต้  
  📞 โทรศัพท์: `088-760-3620`  
  📧 อีเมล: `koki.assawin@gmail.com`

- **สถานศึกษา:**  
  **โรงเรียนเตรียมอุดมศึกษาภาคใต้**  
  สำนักงานเขตพื้นที่การศึกษามัธยมศึกษานครศรีธรรมราช จังหวัดนครศรีธรรมราช  
  🌐 เว็บไซต์โรงเรียน: [http://www.triamudomsouth.ac.th](http://www.triamudomsouth.ac.th)

---

### 📄 เอกสารอ้างอิงและการเผยแพร่
- **รายงานโครงงานฉบับสมบูรณ์:** [รายงานฉบับสมบูรณ์ รหัสโครงการ 28P23S00194.docx](file:///e:/01_Software_Development/Smart%20Song%20theaw/รายงานฉบับสมบูรณ์%20รหัสโครงการ%2028P23S00194_ฉบับสมบูรณ์_สารบัญกระชับ_แก้ไข.docx)
- **โปสเตอร์นำเสนอผลงาน:** [poster SMART SONGTHAEW.pdf](file:///C:/Users/USER/Downloads/poster%20SMART%20SONGTHAEW.pdf)
- **สัญญาอนุญาตสิทธิ์ (License):** เผยแพร่ภายใต้สัญญาอนุญาตสิทธิ์แบบ [MIT License](LICENSE) เพื่อประโยชน์ต่อการศึกษาและสาธารณชน

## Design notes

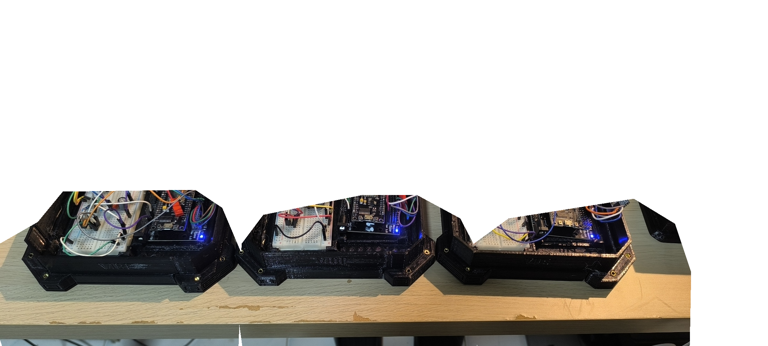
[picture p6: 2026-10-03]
report_assets_hoprelay_devices_cutout_v2.png

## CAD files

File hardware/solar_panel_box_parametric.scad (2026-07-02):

/*
  Parametric 3D printable solar panel enclosure.

  Target:
  - Solar panel: 145 x 145 mm
  - Panel pocket: 146.5 x 146.5 x 3 mm
  - Assembled outside size: 168 x 168 x 40 mm
  - FlashForge Creator Pro build volume: 230 x 150 x 150 mm

  OpenSCAD use:
  1. Set `part` below.
  2. Press F6.
  3. Export STL.

  Large 168 x 84 mm pieces fit the bed one at a time.
  The four top-frame rails can be printed together with `part = "print_frame_set"`.
*/

$fn = 72;

// ---------- Select output ----------
part = "assembly";
// part options:
// "assembly", "print_frame_set",
// "top_frame_front", "top_frame_back", "top_frame_left", "top_frame_right",
// "top_lid_left", "top_lid_right",
// "lower_base_front", "lower_base_back",
// "magnet_base_front", "magnet_base_back",
// "print_top_lid_left", "print_top_lid_right",
// "print_lower_base_front", "print_lower_base_back",
// "print_magnet_base_front", "print_magnet_base_back"

explode = 0;        // Set 8..20 for an exploded assembly preview.
show_bed = true;    // Used by print_* views.

// ---------- Main dimensions ----------
outer_x = 168;
outer_y = 168;
outer_z = 40;

panel_actual = 145;
panel_pocket = 146.5;
pocket_depth = 3;

wall = 3.5;
bottom_floor = 4;

cable_w = 12;
cable_h = 8;

magnet_d = 20;
magnet_depth = 3;

m3_clearance = 3.4;
m3_pilot = 2.8;
m3_head_d = 6.5;
m3_head_h = 2.2;

boss_d = 8.5;

// Z stack. 4 + 23 + 7 + 6 = 40 mm assembled height.
mag_base_h = 4;
lower_base_h = 23;
top_lid_base_h = 7;
top_frame_h = 6;
panel_floor_raise = top_frame_h - pocket_depth; // 3 mm.
top_lid_total_h = top_lid_base_h + panel_floor_raise;

// Fit and alignment features.
fit_clearance = 0.25;
lid_tongue_w = 2.0;
lid_tongue_h = 1.2;
frame_tenon_w = 5.5;
frame_tenon_depth = 4;
frame_tenon_h = 3;

eps = 0.05;

frame_margin = (outer_x - panel_pocket) / 2;
rail_center = outer_x / 2 - frame_margin / 2;
screw_offset = 62;
magnet_offset = 52;

assembled_z = mag_base_h + lower_base_h + top_lid_base_h + top_frame_h;
assert(abs(assembled_z - outer_z) < 0.01, "Z stack must equal 40 mm.");
assert(frame_margin > wall, "Panel pocket leaves too little margin.");

mount_points = [
  [-screw_offset, -rail_center], [ screw_offset, -rail_center],
  [-screw_offset,  rail_center], [ screw_offset,  rail_center],
  [-rail_center, -screw_offset], [-rail_center,  screw_offset],
  [ rail_center, -screw_offset], [ rail_center,  screw_offset]
];

magnet_points = [
  [-magnet_offset, -magnet_offset], [ magnet_offset, -magnet_offset],
  [-magnet_offset,  magnet_offset], [ magnet_offset,  magnet_offset]
];

// ---------- Small helpers ----------
module centered_cube(size) {
  translate([-size[0] / 2, -size[1] / 2, 0])
    cube(size);
}

module screw_hole_at(p, d, h, z = -eps) {
  translate([p[0], p[1], z])
    cylinder(d = d, h = h);
}

module screw_holes(points, d, h, z = -eps) {
  for (p = points)
    screw_hole_at(p, d, h, z);
}

module counterbores(points, body_h) {
  for (p = points)
    translate([p[0], p[1], body_h - m3_head_h + eps])
      cylinder(d = m3_head_d, h = m3_head_h + eps);
}

module bed_outline() {
  if (show_bed) {
    color([0.15, 0.15, 0.15, 0.15])
      translate([-230 / 2, -150 / 2, -0.8])
        cube([230, 150, 0.6]);
  }
}

module half_clip_y(front = true, h = 200) {
  translate([-outer_x / 2 - eps,
             front ? -outer_y / 2 - eps : 0,
             -h / 2])
    cube([outer_x + 2 * eps, outer_y / 2 + eps, h]);
}

module half_clip_x(left = true, h = 200) {
  translate([left ? -outer_x / 2 - eps : 0,
             -outer_y / 2 - eps,
             -h / 2])
    cube([outer_x / 2 + eps, outer_y + 2 * eps, h]);
}

// ---------- Top frame: 4 pieces ----------
module top_frame_front_back(front = true) {
  slot_y = front
    ? frame_margin / 2 - frame_tenon_depth
    : -frame_margin / 2;

  difference() {
    centered_cube([outer_x, frame_margin, top_frame_h]);

    // Cable relief through the front rail. It is open, so it prints without support.
    if (front)
      translate([-cable_w / 2, -frame_margin / 2 - eps, -eps])
        cube([cable_w, frame_margin + 2 * eps, top_frame_h + 2 * eps]);

    // M3 clearance holes with shallow top counterbores.
    screw_holes([[-screw_offset, 0], [screw_offset, 0]],
                m3_clearance, top_frame_h + 2 * eps);
    counterbores([[-screw_offset, 0], [screw_offset, 0]], top_frame_h);

    // Matching slots for tenons on the side rails.
    for (sx = [-1, 1])
      translate([sx * rail_center - frame_tenon_w / 2 - fit_clearance / 2,
                 slot_y - fit_clearance / 2,
                 -eps])
        cube([frame_tenon_w + fit_clearance,
              frame_tenon_depth + fit_clearance,
              frame_tenon_h + eps]);
  }
}

module top_frame_side() {
  difference() {
    union() {
      centered_cube([frame_margin, panel_pocket, top_frame_h]);

      // Low tenons slide into the front/back rail slots.
      for (sy = [-1, 1])
        translate([-frame_tenon_w / 2,
                   sy * panel_pocket / 2 + (sy > 0 ? 0 : -frame_tenon_depth),
                   0])
          cube([frame_tenon_w, frame_tenon_depth, frame_tenon_h]);
    }

    screw_holes([[0, -screw_offset], [0, screw_offset]],
                m3_clearance, top_frame_h + 2 * eps);
    counterbores([[0, -screw_offset], [0, screw_offset]], top_frame_h);
  }
}

// ---------- Top lid: 2 pieces ----------
module alignment_ring(width = lid_tongue_w, height = lid_tongue_h, z = 0) {
  // A shallow tongue/groove ring just inside the wall line.
  // Base uses it as a raised tongue; lid subtracts it as a matching groove.
  tongue_x = outer_x - 2 * wall;
  tongue_y = outer_y - 2 * wall;
  y_pos = outer_y / 2 - wall - width / 2;
  x_pos = outer_x / 2 - wall - width / 2;

  translate([0, -y_pos, z])
    centered_cube([tongue_x, width, height]);
  translate([0, y_pos, z])
    centered_cube([tongue_x, width, height]);
  translate([-x_pos, 0, z])
    centered_cube([width, tongue_y, height]);
  translate([x_pos, 0, z])
    centered_cube([width, tongue_y, height]);
}

module top_lid_full() {
  difference() {
    union() {
      // Main cover plate.
      centered_cube([outer_x, outer_y, top_lid_base_h]);

      // Raised panel floor. Top of this pad is 3 mm below the top frame.
      translate([0, 0, top_lid_base_h])
        centered_cube([panel_pocket, panel_pocket, panel_floor_raise]);

    }

    // M3 clearance holes through the lid.
    screw_holes(mount_points, m3_clearance,
                top_lid_total_h + 2 * eps);

    // Matching underside groove for the raised tongue on the lower base.
    alignment_ring(lid_tongue_w + fit_clearance,
                   lid_tongue_h + eps,
                   -eps);

    // Front open wire relief aligns with the front frame and lower base cable notch.
    translate([-cable_w / 2, -outer_y / 2 - eps, -eps])
      cube([cable_w,
            frame_margin + wall + 2 * eps,
            top_lid_total_h + 2 * eps]);
  }
}

module top_lid_half(left = true) {
  intersection() {
    top_lid_full();
    half_clip_x(left, 240);
  }
}

// ---------- Lower base: 2 pieces ----------
module base_shell() {
  difference() {
    centered_cube([outer_x, outer_y, lower_base_h]);
    translate([-outer_x / 2 + wall,
               -outer_y / 2 + wall,
               bottom_floor])
      cube([outer_x - 2 * wall,
            outer_y - 2 * wall,
            lower_base_h - bottom_floor + eps]);
  }
}

module lower_base_full() {
  difference() {
    union() {
      base_shell();

      // Internal bosses for M3 self-tapping screws or heat-set inserts.
      for (p = mount_points)
        translate([p[0], p[1], 0])
          cylinder(d = boss_d, h = lower_base_h);

      alignment_ring(lid_tongue_w, lid_tongue_h, lower_base_h - lid_tongue_h);
    }

    // M3 pilot holes in bosses.
    screw_holes(mount_points, m3_pilot, lower_base_h + 2 * eps);

    // 12 x 8 mm front cable notch, open at the top to avoid support.
    translate([-cable_w / 2,
               -outer_y / 2 - eps,
               lower_base_h - cable_h])
      cube([cable_w, wall + 2 * eps, cable_h + eps]);
  }
}

module lower_base_half(front = true) {
  intersection() {
    lower_base_full();
    half_clip_y(front, 240);
  }
}

// ---------- Magnet base: 2 pieces ----------
module magnet_base_full() {
  difference() {
    centered_cube([outer_x, outer_y, mag_base_h]);

    // Four magnet cups, open on the bottom face. Print this part pocket-side up,
    // then flip it during assembly so the magnets face outward.
    for (p = magnet_points)
      translate([p[0], p[1], -eps])
        cylinder(d = magnet_d, h = magnet_depth + eps);

    // Optional M3 clearance holes aligned to the main assembly screws.
    screw_holes(mount_points, m3_clearance, mag_base_h + 2 * eps);
    for (p = mount_points)
      translate([p[0], p[1], -eps])
        cylinder(d = m3_head_d, h = m3_head_h + eps);
  }
}

module magnet_base_half(front = true) {
  intersection() {
    magnet_base_full();
    half_clip_y(front, 240);
  }
}
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

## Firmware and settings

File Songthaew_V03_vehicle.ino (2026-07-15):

// Songthaew_V03_vehicle.ino
/*
  Smart Songthaew VIBE Mesh - Vehicle Firmware V03

  ESP8266 NodeMCU -> SX1276 Ra-02
  D5 (GPIO14) -> SCK
  D6 (GPIO12) -> MISO
  D7 (GPIO13) -> MOSI
  D8 (GPIO15) -> NSS/CS
  D0 (GPIO16) -> RESET
  D2 (GPIO4)  -> DIO0
  3V3         -> VCC
  GND         -> GND

  ESP8266 NodeMCU -> NEO-6M GPS
  D4 (GPIO2)  -> GPS TX (we receive)
  3V3         -> VCC
  GND         -> GND
  GPS RX and PPS are not connected

  Battery sense voltage divider:
  BAT+ -> 330k ohm -> A0 -> 82k ohm -> GND
  100nF capacitor across 82k ohm
*/

#include <Arduino.h>
#include <ArduinoJson.h>
#include <LoRa.h>
#include <SoftwareSerial.h>
#include <SPI.h>
#include <TinyGPS++.h>
#include <ESP8266WiFi.h>
#include <math.h>
#if defined(SONGTHAEW_CI_BUILD)
#include "songthaew_secrets.example.h"
#elif __has_include("songthaew_secrets.h")
#include "songthaew_secrets.h"
#else
#error "Create songthaew_secrets.h from songthaew_secrets.example.h before flashing."
#endif
#include "mesh_config.h"

struct Neighbor {
  char vehicleId[16];
  float rssi;
  float snr;
  unsigned long lastSeen;
  float lat;
  float lng;
  int hop;
};

struct VehicleState {
  char vehicleId[16];
  char bootId[5];
  char packetId[40];
  uint32_t seq;
  uint32_t gpsTs;
  float lat;
  float lng;
  float speed;
  int heading;
  int battery;
  int hop;
  bool gpsFix;
  bool used;
  unsigned long lastSeen;
};

struct PendingRelay {
  char packetId[64];
  char payload[MAX_LORA_PACKET_BYTES + 1];
  unsigned long dueAt;
  bool used;
};

TinyGPSPlus gps;
SoftwareSerial gpsSerial(GPS_RX_PIN, -1);

Neighbor neighbors[MAX_NEIGHBORS];
int neighborCount = 0;

VehicleState sharedStates[SHARED_STATE_SIZE];
PendingRelay pendingRelays[RELAY_QUEUE_SIZE];

char seenPackets[DEDUP_BUFFER][40];
int seenIdx = 0;

char bootId[5] = "0000";
uint32_t seq = 0;

float gpsLat = 0.0f;
float gpsLng = 0.0f;
float gpsSpeed = 0.0f;
float gpsHeading = 0.0f;
bool gpsValid = false;
bool gpsTimeValid = false;
uint32_t gpsTimestamp = 0;

unsigned long nextTxMs = 0;
unsigned long lastExpireMs = 0;
unsigned long lastLoRaRetryMs = 0;
unsigned long lastBatteryPrintMs = 0;
const char* nextTxMode = "fallback";
bool loraReady = false;


float toRadians(float degrees) {
  return degrees * PI / 180.0f;
}

float haversineDistance(float lat1, float lng1, float lat2, float lng2) {
  const float radiusMeters = 6371000.0f;
  float dLat = toRadians(lat2 - lat1);
  float dLng = toRadians(lng2 - lng1);
  float a = sin(dLat / 2.0f) * sin(dLat / 2.0f) +
            cos(toRadians(lat1)) * cos(toRadians(lat2)) *
            sin(dLng / 2.0f) * sin(dLng / 2.0f);
  float c = 2.0f * atan2(sqrt(a), sqrt(1.0f - a));
  return radiusMeters * c;
}

bool isLeapYear(uint16_t year) {
  return (year % 4 == 0 && year % 100 != 0) || (year % 400 == 0);
}

uint32_t gpsUnixTimestamp() {
  if (!gps.date.isValid() || !gps.time.isValid()) return 0;
  if (gps.date.age() > 2000 || gps.time.age() > 2000) return 0;

  static const uint8_t daysBeforeMonth[] = { 0, 31, 59, 90, 120, 151, 181, 212, 243, 273, 304, 334 };
  uint16_t year = gps.date.year();
  uint8_t month = gps.date.month();
  uint8_t day = gps.date.day();
  if (year < 2020 || month < 1 || month > 12 || day < 1 || day > 31) return 0;

  uint32_t days = 0;
  for (uint16_t y = 1970; y < year; y++) {
    days += isLeapYear(y) ? 366UL : 365UL;
  }
  days += daysBeforeMonth[month - 1];
  if (month > 2 && isLeapYear(year)) days++;
  days += day - 1;

  return days * 86400UL +
         (uint32_t)gps.time.hour() * 3600UL +
         (uint32_t)gps.time.minute() * 60UL +
         (uint32_t)gps.time.second();
}

int linkQuality(float rssi, float snr) {
  int lq = constrain(map((long)rssi, -120, -60, 0, 100), 0, 100);
  if (snr < 0.0f) lq = constrain(lq - 10, 0, 100);
  return lq;
}

bool sameId(const char* a, const char* b) {
  return strncmp(a, b, 15) == 0;
}

// Returns true if this vehicle is a forced-hop origin (source or any relay that
// must forward its own telemetry through the chain rather than directly to Ground).
bool isForcedHopTestSource() {
  if (!FORCED_HOP_TEST_ENABLED) return false;
  // SOURCE (BUS_03) and RELAY_1 (BUS_02) both transmit with forced-hop enabled;
  // RELAY_2 (BUS_01) sends its own telemetry directly.
  return sameId(VEHICLE_ID, FORCED_HOP_TEST_SOURCE) ||
         sameId(VEHICLE_ID, FORCED_HOP_TEST_RELAY_1);
}

// For a given relay node, returns its next hop target in the forced chain.
// SOURCE -> RELAY_1, RELAY_1 -> RELAY_2, RELAY_2 -> Ground (out="", returns true).
bool forcedHopNextTargetFor(const char* relayId, char* out, size_t outSize) {
  if (outSize == 0) return false;
  out[0] = '\0';
  if (!FORCED_HOP_TEST_ENABLED || relayId == nullptr) return false;
  if (sameId(relayId, FORCED_HOP_TEST_SOURCE)) {
    strncpy(out, FORCED_HOP_TEST_RELAY_1, outSize - 1);
    out[outSize - 1] = '\0';
    return true;
  }
  if (sameId(relayId, FORCED_HOP_TEST_RELAY_1)) {
    strncpy(out, FORCED_HOP_TEST_RELAY_2, outSize - 1);
    out[outSize - 1] = '\0';
    return true;
  }
  if (sameId(relayId, FORCED_HOP_TEST_RELAY_2)) return true;
  return false;
}

int vehicleNumberFromId(const char* id) {
  if (id == nullptr || strncmp(id, "BUS_", 4) != 0) return 0;
  int number = atoi(id + 4);
  return number >= 1 && number <= VEHICLE_COUNT ? number : 0;
}

int vehicleNumber() {
  return vehicleNumberFromId(VEHICLE_ID);
}

unsigned long vehicleTxOffsetMs() {
  int number = vehicleNumber();
  int slot = number > 0 ? number - 1 : 0;
  return (unsigned long)slot * TX_SLOT_SPACING_MS;
}

unsigned long txJitterMs() {
  return TX_JITTER_MS > 0 ? (unsigned long)random(0, TX_JITTER_MS + 1) : 0;
}

void scheduleNextTx(unsigned long baseMs, const char* mode = "fallback") {
  nextTxMs = baseMs + TX_INTERVAL_MS + txJitterMs();
  nextTxMode = mode;
}

void syncTxSlotFromBeacon(unsigned long beaconRxMs) {
  nextTxMs = beaconRxMs + TX_SYNC_GUARD_MS + vehicleTxOffsetMs() + txJitterMs();
  nextTxMode = "beacon";
}

bool neighborExpired(const Neighbor& neighbor, unsigned long now) {
  return now - neighbor.lastSeen > NEIGHBOR_EXPIRE_MS;
}

int findNeighborIndex(const char* id) {
  for (int i = 0; i < neighborCount; i++) {
    if (sameId(neighbors[i].vehicleId, id)) return i;
  }
  return -1;
}

void updateNeighborWithHop(const char* id, float rssi, float snr, float lat, float lng, int hop) {
  if (id == nullptr || id[0] == '\0' || sameId(id, VEHICLE_ID)) return;

  int index = findNeighborIndex(id);
  if (index < 0) {
    if (neighborCount < MAX_NEIGHBORS) {
      index = neighborCount++;
    } else {
      unsigned long oldestSeen = neighbors[0].lastSeen;
      index = 0;
      for (int i = 1; i < MAX_NEIGHBORS; i++) {
        if (neighbors[i].lastSeen < oldestSeen) {
          oldestSeen = neighbors[i].lastSeen;
          index = i;
        }
      }
    }
  }

  strncpy(neighbors[index].vehicleId, id, sizeof(neighbors[index].vehicleId) - 1);
  neighbors[index].vehicleId[sizeof(neighbors[index].vehicleId) - 1] = '\0';
  neighbors[index].rssi = rssi;
  neighbors[index].snr = snr;
  neighbors[index].lastSeen = millis();
  neighbors[index].lat = lat;
  neighbors[index].lng = lng;
  neighbors[index].hop = hop;
}

void updateNeighbor(const char* id, float rssi, float snr, float lat, float lng) {
  updateNeighborWithHop(id, rssi, snr, lat, lng, 0);
}

void expireNeighbors() {
  unsigned long now = millis();
  for (int i = 0; i < neighborCount; i++) {
    if (neighborExpired(neighbors[i], now)) {
      neighbors[i] = neighbors[neighborCount - 1];
      neighborCount--;
      i--;
    }
  }
}

Neighbor* findBestRelay() {
  Neighbor* best = nullptr;
  float bestDistance = 999999999.0f;
  unsigned long now = millis();
  float myDistance = gpsValid ? haversineDistance(gpsLat, gpsLng, GROUND_LAT, GROUND_LNG) : 999999999.0f;

  for (int i = 0; i < neighborCount; i++) {
    if (neighborExpired(neighbors[i], now)) continue;
    if (sameId(neighbors[i].vehicleId, GROUND_ID)) continue;
    if (neighbors[i].lat == 0.0f && neighbors[i].lng == 0.0f) continue;
    if (linkQuality(neighbors[i].rssi, neighbors[i].snr) < MIN_RELAY_LINK_QUALITY) continue;

    float distance = haversineDistance(neighbors[i].lat, neighbors[i].lng, GROUND_LAT, GROUND_LNG);
    if (gpsValid && distance + RELAY_DISTANCE_MARGIN_M >= myDistance) continue;
    if (distance < bestDistance) {
      bestDistance = distance;
      best = &neighbors[i];
    }
  }
  return best;
}

Neighbor* findGroundStation() {
  int index = findNeighborIndex(GROUND_ID);
  if (index < 0) return nullptr;
  if (neighborExpired(neighbors[index], millis())) return nullptr;
  return &neighbors[index];
}

bool isGroundStationNearby() {
  return findGroundStation() != nullptr;
}

bool alreadySeen(const char* packetId) {
  if (packetId == nullptr || packetId[0] == '\0') return false;
  for (int i = 0; i < DEDUP_BUFFER; i++) {
    if (strncmp(seenPackets[i], packetId, sizeof(seenPackets[i])) == 0) return true;
  }
  return false;
}

void markSeen(const char* packetId) {
  if (packetId == nullptr || packetId[0] == '\0' || alreadySeen(packetId)) return;
  strncpy(seenPackets[seenIdx], packetId, sizeof(seenPackets[seenIdx]) - 1);
  seenPackets[seenIdx][sizeof(seenPackets[seenIdx]) - 1] = '\0';
  seenIdx = (seenIdx + 1) % DEDUP_BUFFER;
}

void buildPacketId(char* out, size_t outSize) {
  snprintf(out, outSize, "%s_%lu_%s_%lu",
           VEHICLE_ID, (unsigned long)seq, bootId, (unsigned long)gpsTimestamp);
}

int findSharedStateIndex(const char* id) {
  if (id == nullptr || id[0] == '\0') return -1;
  for (int i = 0; i < SHARED_STATE_SIZE; i++) {
    if (sharedStates[i].used && sameId(sharedStates[i].vehicleId, id)) return i;
  }
  return -1;
}

int sharedStateSlotFor(const char* id) {
  int index = findSharedStateIndex(id);
  if (index >= 0) return index;

  for (int i = 0; i < SHARED_STATE_SIZE; i++) {
    if (!sharedStates[i].used) return i;
  }

  int oldest = 0;
  for (int i = 1; i < SHARED_STATE_SIZE; i++) {
    if (sharedStates[i].lastSeen < sharedStates[oldest].lastSeen) oldest = i;
  }
  return oldest;
}

bool packetIsNewer(const VehicleState& state, const char* bid, uint32_t rxSeq, uint32_t rxGpsTs) {
  if (!state.used) return true;
  if (strncmp(state.bootId, bid, sizeof(state.bootId)) != 0) {
    if (rxGpsTs > 0 && state.gpsTs > 0) return rxGpsTs >= state.gpsTs;
    if (rxGpsTs > 0 && state.gpsTs == 0) return true;
    if (rxGpsTs == 0 && state.gpsTs > 0) return false;
    return true;
  }
  if (rxSeq > state.seq) return true;
  if (rxSeq == state.seq && rxGpsTs > state.gpsTs) return true;
  return false;
}

void writeSharedState(int index, const char* vid, const char* bid, const char* pid,
                      uint32_t rxSeq, uint32_t rxGpsTs, float lat, float lng,
                      float speed, int heading, int battery, int hop, bool fix) {
  if (index < 0 || index >= SHARED_STATE_SIZE) return;

  strncpy(sharedStates[index].vehicleId, vid, sizeof(sharedStates[index].vehicleId) - 1);
  sharedStates[index].vehicleId[sizeof(sharedStates[index].vehicleId) - 1] = '\0';
  strncpy(sharedStates[index].bootId, bid, sizeof(sharedStates[index].bootId) - 1);
  sharedStates[index].bootId[sizeof(sharedStates[index].bootId) - 1] = '\0';
  strncpy(sharedStates[index].packetId, pid, sizeof(sharedStates[index].packetId) - 1);
  sharedStates[index].packetId[sizeof(sharedStates[index].packetId) - 1] = '\0';
  sharedStates[index].seq = rxSeq;
  sharedStates[index].gpsTs = rxGpsTs;
  sharedStates[index].lat = lat;
  sharedStates[index].lng = lng;
  sharedStates[index].speed = speed;
  sharedStates[index].heading = heading;
  sharedStates[index].battery = battery;
  sharedStates[index].hop = hop;
  sharedStates[index].gpsFix = fix;
  sharedStates[index].used = true;
  sharedStates[index].lastSeen = millis();
}

bool updateSharedStateFromDoc(JsonDocument& doc) {
  const char* vid = doc["vid"] | "";
  const char* bid = doc["bid"] | "";
  const char* pid = doc["pid"] | "";
  if (vid[0] == '\0' || bid[0] == '\0' || pid[0] == '\0') return false;

  uint32_t rxSeq = doc["seq"] | 0UL;
  uint32_t rxGpsTs = doc["gt"] | 0UL;
  int index = sharedStateSlotFor(vid);
  if (!packetIsNewer(sharedStates[index], bid, rxSeq, rxGpsTs)) return false;

  writeSharedState(index, vid, bid, pid, rxSeq, rxGpsTs,
                   doc["lat"] | 0.0f, doc["lng"] | 0.0f,
                   doc["spd"] | 0.0f, doc["hdg"] | 0,
                   doc["bat"] | -1, doc["hop"] | 0, doc["fix"] | false);
  return true;
}

void updateOwnSharedState(const char* packetId, int battery, int hop) {
  int index = sharedStateSlotFor(VEHICLE_ID);
  writeSharedState(index, VEHICLE_ID, bootId, packetId, seq, gpsTimestamp,
                   gpsValid ? gpsLat : 0.0f, gpsValid ? gpsLng : 0.0f,
                   gpsSpeed, (int)gpsHeading, battery, hop, gpsValid);
}

void updateKnownVehicle(const char* vehicleId, const char* shortId,
                        uint32_t rxSeq, const char* rxBootId) {
  if (vehicleId == nullptr || vehicleId[0] == '\0') return;
  if (sameId(vehicleId, VEHICLE_ID)) return;

  const char* safeBootId = rxBootId ? rxBootId : "";
  int index = sharedStateSlotFor(vehicleId);
  VehicleState& state = sharedStates[index];
  if (state.used && sameId(state.vehicleId, vehicleId) &&
      strncmp(state.bootId, safeBootId, sizeof(state.bootId)) == 0 &&
      rxSeq < state.seq) {
    return;
  }

  strncpy(state.vehicleId, vehicleId, sizeof(state.vehicleId) - 1);
  state.vehicleId[sizeof(state.vehicleId) - 1] = '\0';
  strncpy(state.bootId, safeBootId, sizeof(state.bootId) - 1);
  state.bootId[sizeof(state.bootId) - 1] = '\0';
  state.seq = rxSeq;
  state.used = true;
  state.lastSeen = millis();
  (void)shortId;
}

void addVersionSummary(JsonDocument& doc) {
  JsonArray summary = doc.createNestedArray("vs");
  int added = 0;
  for (int i = 0; i < SHARED_STATE_SIZE && added < VERSION_SUMMARY_LIMIT; i++) {
    if (!sharedStates[i].used || sameId(sharedStates[i].vehicleId, VEHICLE_ID)) continue;
    JsonArray item = summary.createNestedArray();
    item.add(sharedStates[i].vehicleId);
    item.add(sharedStates[i].seq);
    if (sharedStates[i].gpsTs > 0) item.add(sharedStates[i].gpsTs);
    added++;
  }
  if (added == 0) doc.remove("vs");
}

void fullVehicleIdFromShortToBuffer(const char* shortId, char* out, size_t outSize) {
  if (outSize == 0) return;
  out[0] = '\0';
  if (shortId == nullptr || shortId[0] == '\0') return;

  int number = atoi(shortId + 1);
  if (shortId[0] == 'B') {
    snprintf(out, outSize, "BUS_%02d", number);
    return;
  }
  if (shortId[0] == 'D') {
    snprintf(out, outSize, "DEMO_%d", number);
    return;
  }
  if (shortId[0] == 'G') {
    snprintf(out, outSize, "GROUND_%02d", number);
    return;
  }
  strncpy(out, shortId, outSize - 1);
  out[outSize - 1] = '\0';
}

const char* directionCode(const char* direction) {
  if (direction == nullptr || direction[0] == '\0') return "U";
  char c = direction[0];
  if (c == 'i' || c == 'I') return "I";
  if (c == 'o' || c == 'O') return "O";
  return "U";
}

void packetHash6ToBuffer(const char* packetId, char* out, size_t outSize) {
  if (outSize == 0) return;
  out[0] = '\0';
  uint32_t hash = 2166136261UL;
  if (packetId != nullptr) {
    while (*packetId) {
      hash ^= (uint8_t)*packetId++;
      hash *= 16777619UL;
    }
  }
  snprintf(out, outSize, "%06lX", (unsigned long)(hash & 0xFFFFFFUL));
}

void shortVehicleIdToBuffer(const char* vehicleId, char* out, size_t outSize) {
  if (outSize == 0) return;
  out[0] = '\0';
  if (vehicleId == nullptr || vehicleId[0] == '\0') return;

  if (strncmp(vehicleId, "DEMO_", 5) == 0) {
    snprintf(out, outSize, "D%d", atoi(vehicleId + 5));
    return;
  }
  if (strncmp(vehicleId, "BUS_", 4) == 0) {
    snprintf(out, outSize, "B%d", atoi(vehicleId + 4));
    return;
  }
  if (strncmp(vehicleId, "GROUND_", 7) == 0) {
    snprintf(out, outSize, "G%d", atoi(vehicleId + 7));
    return;
  }

  size_t write = 0;
  for (size_t read = 0; vehicleId[read] != '\0' && write < outSize - 1 && write < 6; read++) {
    if (vehicleId[read] == '_') continue;
    out[write++] = vehicleId[read];
  }
  out[write] = '\0';
}

void shortRouteIdToBuffer(const char* routeId, char* out, size_t outSize) {
  if (outSize == 0) return;
  out[0] = '\0';
  if (routeId == nullptr || routeId[0] == '\0') return;
  if (strncmp(routeId, "route_", 6) == 0) {
    snprintf(out, outSize, "R%d", atoi(routeId + 6));
    return;
  }

  size_t write = 0;
  for (size_t read = 0; routeId[read] != '\0' && write < outSize - 1 && write < 8; read++) {
    if (routeId[read] == '_' || routeId[read] == '-') continue;
    if (strncmp(routeId + read, "route", 5) == 0) {
      out[write++] = 'R';
      read += 4;
      continue;
    }
    out[write++] = routeId[read];
  }
  out[write] = '\0';
}

void appendCompactToken(char* out, size_t outSize, const char* token) {
  if (outSize == 0 || token == nullptr || token[0] == '\0') return;
  size_t used = strlen(out);
  if (used >= outSize - 1) return;
  snprintf(out + used, outSize - used, "%s%s", used > 0 ? "," : "", token);
}

bool compactListContains(const char* list, const char* token) {
  if (list == nullptr || token == nullptr || token[0] == '\0') return false;
  const char* start = list;
  size_t tokenLength = strlen(token);
  while (*start != '\0') {
    const char* comma = strchr(start, ',');
    size_t length = comma ? (size_t)(comma - start) : strlen(start);
    if (length == tokenLength && strncmp(start, token, length) == 0) return true;
    if (comma == nullptr) break;
    start = comma + 1;
  }
  return false;
}

void trimCompactListTo(char* out, size_t maxLen) {
  while (strlen(out) > maxLen) {
    char* comma = strchr(out, ',');
    if (comma == nullptr) {
      size_t len = strlen(out);
      memmove(out, out + len - maxLen, maxLen + 1);
      return;
    }
    memmove(out, comma + 1, strlen(comma + 1) + 1);
  }
}

void buildNeighborCompact(char* out, size_t outSize, Neighbor* table, int count) {
  if (outSize == 0) return;
  out[0] = '\0';
  int best[3] = { -1, -1, -1 };
  unsigned long now = millis();

  for (int i = 0; i < count; i++) {
    if (neighborExpired(table[i], now)) continue;
    if (sameId(table[i].vehicleId, GROUND_ID)) continue;

    for (int slot = 0; slot < 3; slot++) {
      if (best[slot] < 0 || table[i].rssi > table[best[slot]].rssi) {
        for (int shift = 2; shift > slot; shift--) best[shift] = best[shift - 1];
        best[slot] = i;
        break;
      }
    }
  }

  for (int slot = 0; slot < 3; slot++) {
    int index = best[slot];
    if (index < 0) continue;
    char shortId[8];
    char token[32];
    shortVehicleIdToBuffer(table[index].vehicleId, shortId, sizeof(shortId));
    snprintf(token, sizeof(token), "%s:%d:%d", shortId, (int)table[index].rssi, (int)round(table[index].snr * 10.0f));
    appendCompactToken(out, outSize, token);
  }
}

void buildRelayChainCompactFromDoc(JsonDocument& doc, char* out, size_t outSize) {
  if (outSize == 0) return;
  out[0] = '\0';

  if (doc["rc"].is<JsonArray>()) {
    for (JsonVariant item : doc["rc"].as<JsonArray>()) {
      char shortId[8];
      shortVehicleIdToBuffer(item.as<const char*>(), shortId, sizeof(shortId));
      if (shortId[0] == '\0' || compactListContains(out, shortId)) continue;
      appendCompactToken(out, outSize, shortId);
    }
  }

  const char* relayFrom = doc["rf"] | "";
  if (relayFrom[0] != '\0') {
    char shortId[8];
    shortVehicleIdToBuffer(relayFrom, shortId, sizeof(shortId));
    if (shortId[0] != '\0' && !compactListContains(out, shortId)) appendCompactToken(out, outSize, shortId);
  }
  trimCompactListTo(out, 30);
}

void buildVersionSummaryCompact(char* out, size_t outSize) {
  if (outSize == 0) return;
  out[0] = '\0';
  unsigned long now = millis();
  int added = 0;
  for (int i = 0; i < SHARED_STATE_SIZE && added < VERSION_SUMMARY_LIMIT; i++) {
    if (!sharedStates[i].used || sameId(sharedStates[i].vehicleId, VEHICLE_ID)) continue;
    if (now - sharedStates[i].lastSeen > MESH_SEEN_TIMEOUT_MS) continue;
    char shortId[8];
    char bootPrefix[3] = "";
    char token[32];
    shortVehicleIdToBuffer(sharedStates[i].vehicleId, shortId, sizeof(shortId));
    if (strlen(sharedStates[i].bootId) >= 2) {
      bootPrefix[0] = sharedStates[i].bootId[0];
      bootPrefix[1] = sharedStates[i].bootId[1];
      bootPrefix[2] = '\0';
    } else {
      strncpy(bootPrefix, sharedStates[i].bootId, sizeof(bootPrefix) - 1);
    }
    snprintf(token, sizeof(token), "%s:%lu:%s", shortId, (unsigned long)sharedStates[i].seq, bootPrefix);
    appendCompactToken(out, outSize, token);
    added++;
  }
}
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
void loop() {
  readGPS();

  if (!loraReady && millis() - lastLoRaRetryMs >= 5000UL) {
    lastLoRaRetryMs = millis();
    loraReady = initLoRa();
  }

  if (loraReady) {
    int packetSize = LoRa.parsePacket();
    if (packetSize > 0) onLoRaReceive(packetSize);
  }

  unsigned long now = millis();
  if (now - lastExpireMs >= EXPIRE_INTERVAL_MS) {
    lastExpireMs = now;
    expireNeighbors();
  }

  if (now - lastBatteryPrintMs >= 5000UL) {
    lastBatteryPrintMs = now;
    printBatteryStatus();
  }

  servicePendingRelays();

  if ((long)(now - nextTxMs) >= 0) {
    transmitPacket(nextTxMode);
    scheduleNextTx(now);
  }

  yield();
}

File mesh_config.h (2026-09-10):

// mesh_config.h - safe to commit
// Non-secret hardware, LoRa, timing, and mesh settings.
// Put WiFi credentials, server URL, vehicle ID, route ID, and route direction in songthaew_secrets.h.

#ifndef MESH_CONFIG_H
#define MESH_CONFIG_H

// Ground station location (can be overridden in songthaew_secrets.h)
#ifndef GROUND_LAT
#define GROUND_LAT    8.4304
#endif
#ifndef GROUND_LNG
#define GROUND_LNG    99.9631
#endif
#ifndef GROUND_ID
#define GROUND_ID     "GROUND_01"
#endif

// Vehicles
#define VEHICLE_COUNT   3

// LoRa pin mapping: ESP8266 NodeMCU + SX1276/Ra-02
#define LORA_SS_PIN    15   // D8
#define LORA_RST_PIN   16   // D0
#define LORA_DIO0_PIN   4   // D2
#define LORA_SS         LORA_SS_PIN
#define LORA_RST        LORA_RST_PIN
#define LORA_DIO0       LORA_DIO0_PIN

// LoRa RF settings
#define LORA_FREQ       923E6
#define LORA_BW         125E3
#define LORA_SF         7
#define LORA_CR         5
#define LORA_SYNC       0x34
#define LORA_TX_DBM     17

// Packet size limit
#define MAX_LORA_PACKET_BYTES 200

// GPS
#define GPS_RX_PIN      2    // D4 <- GPS TX
#define GPS_BAUD        9600

// Battery sense voltage divider
#define BAT_PIN         A0

// TDMA and timing
#define TX_INTERVAL_MS        5000UL
#define TX_SLOT_SPACING_MS    500UL
#define TX_JITTER_MS          30UL
#define TX_SYNC_GUARD_MS      100UL
#define BEACON_INTERVAL_MS    TX_INTERVAL_MS
#define RELAY_WINDOW_START_MS 1600UL
#define RELAY_SLOT_SPACING_MS 350UL
#define RELAY_SLOT_COUNT      VEHICLE_COUNT
#define GROUND_RX_WINDOW_MS   3000UL
#define GROUND_HTTP_TIMEOUT_MS 3500UL
#define GROUND_BATCH_SIZE     6
#define NEIGHBOR_EXPIRE_MS    30000UL
#define WIFI_RETRY_MS         15000UL
#define WIFI_SETUP_TIMEOUT_MS 20000UL
#define EXPIRE_INTERVAL_MS    5000UL

// Mesh sizing
#define MAX_NEIGHBORS         10
#define SHARED_STATE_SIZE     10
#define VERSION_SUMMARY_LIMIT 5
#define RELAY_QUEUE_SIZE      4
#define DEDUP_BUFFER          10
#define BUFFER_SIZE           40
#define MAX_HOPS              2
#define MESH_SEEN_TIMEOUT_MS  NEIGHBOR_EXPIRE_MS

// Relay policy
#define RELAY_DISTANCE_MARGIN_M 20.0f
#define MIN_RELAY_LINK_QUALITY  20

// Forced-hop test (disabled in normal operation).
// When enabled, telemetry from FORCED_HOP_TEST_SOURCE must travel through
// FORCED_HOP_TEST_RELAY_1 and FORCED_HOP_TEST_RELAY_2 before Ground accepts it.
#define FORCED_HOP_TEST_ENABLED       0
#define FORCED_HOP_TEST_SOURCE        "BUS_03"
#define FORCED_HOP_TEST_RELAY_1       "BUS_02"
#define FORCED_HOP_TEST_RELAY_2       "BUS_01"
#define FORCED_HOP_TEST_EXPECTED_HOPS 2
#define FORCED_HOP_TEST_RX_EXTRA_MS   1500UL
#define FORCED_HOP_TEST_RELAY_DELAY_MS 400UL

// Power Management
#define PWR_EN_PIN              0     // D3 / GPIO0 - IRF9540N Gate
#define PWR_ON                  LOW   // LOW = MOSFET conducts = power ON

#endif // MESH_CONFIG_H

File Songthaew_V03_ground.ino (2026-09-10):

// Songthaew_V03_ground.ino
/*
  Smart Songthaew VIBE Mesh - Ground Station Firmware V03

  ESP8266 NodeMCU -> SX1276 Ra-02
  D5 (GPIO14) -> SCK
  D6 (GPIO12) -> MISO
  D7 (GPIO13) -> MOSI
  D8 (GPIO15) -> NSS/CS
  D0 (GPIO16) -> RESET
  D2 (GPIO4)  -> DIO0
  3V3         -> VCC
  GND         -> GND

  Power: USB 5V -> NodeMCU USB port
  WiFi: connects to WIFI_SSID from songthaew_secrets.h
*/

#include <Arduino.h>
#include <ArduinoJson.h>
#include <ESP8266HTTPClient.h>
#include <ESP8266WiFi.h>
#include <LoRa.h>
#include <SPI.h>
#include <WiFiClientSecure.h>
#if defined(SONGTHAEW_CI_BUILD)
#include "songthaew_secrets.example.h"
#elif __has_include("songthaew_secrets.h")
#include "songthaew_secrets.h"
#else
#error "Create songthaew_secrets.h from songthaew_secrets.example.h before flashing."
#endif
#include "mesh_config.h"

#ifndef GROUND_KEY
#define GROUND_KEY ""
#endif

struct BufferedPacket {
  char payload[MAX_LORA_PACKET_BYTES + 1];
  float rssi;
  float snr;
  bool used;
  uint8_t attempts;
  unsigned long timestamp;
};

#define DEDUP_CACHE_SIZE 12
#define DEDUP_EXPIRE_MS  30000UL
#define DEDUP_PACKET_ID_LEN 48
#define SEEN_VEHICLE_SIZE VEHICLE_COUNT
#define SEEN_VEHICLE_EXPIRE_MS 90000UL
#define GROUND_RX_QUIET_MS 500UL
#define GROUND_HTTP_FLUSH_INTERVAL_MS 500UL
#define GROUND_METRICS_INTERVAL_MS 30000UL

struct DedupEntry {
  char packetId[DEDUP_PACKET_ID_LEN];
  uint32_t seenAtMs;
};

struct SeenVehicle {
  char vehicleId[16];
  float rssi;
  float snr;
  unsigned long lastSeenMs;
  uint32_t rxCount;
  bool used;
};

BufferedPacket packetBuffer[BUFFER_SIZE];
DedupEntry dedupCache[DEDUP_CACHE_SIZE];
SeenVehicle seenVehicles[SEEN_VEHICLE_SIZE];
int dedupHead = 0;

bool wifiConnected = false;
bool loraReady = false;
unsigned long lastWifiCheckMs = 0;
unsigned long lastBeaconMs = 0;
unsigned long lastFlushMs = 0;
unsigned long lastBatchBeaconMs = 0;
unsigned long lastLoRaRetryMs = 0;
unsigned long lastHttpLatencyMs = 0;
unsigned long ledPulseUntilMs = 0;
unsigned long lastRxMs = 0;
bool ledPulseActive = false;
uint8_t consecutiveHttpFailures = 0;
unsigned long lastForcedWifiReconnectMs = 0;
unsigned long lastMetricsMs = 0;
uint32_t packetsQueued = 0;
uint32_t packetsSent = 0;
uint32_t packetsRetried = 0;
uint32_t packetsDropped = 0;

bool isVehiclePacket(JsonDocument& doc) {
  const char* type = doc["type"] | "";
  const char* compactType = doc["t"] | "";
  return strcmp(type, "vehicle_data") == 0 || strcmp(compactType, "vd") == 0;
}

bool isValidForcedHopCompletion(JsonDocument& doc, bool compactPacket) {
  int hop = doc["hop"] | -1;
  // For compact-decoded packets the relay_from field holds the full ID;
  // for raw (non-compact) expanded packets it is stored under "rf".
  const char* relayFrom = compactPacket ? (doc["relay_from"] | "") : (doc["rf"] | "");
  const char* vehicleId = compactPacket ? (doc["vehicleId"] | "") : (doc["vid"] | "");

  // All forced-hop completions must arrive via RELAY_2 (BUS_01).
  if (strcmp(relayFrom, FORCED_HOP_TEST_RELAY_2) != 0) return false;

  // Case A: RELAY_1 (BUS_02) packet — 1-hop path: BUS_02 -> BUS_01 -> Ground.
  //         hop == 1, source is RELAY_1, relay chain need only contain RELAY_2.
  if (strcmp(vehicleId, FORCED_HOP_TEST_RELAY_1) == 0) {
    return hop == 1;
  }

  // Case B: SOURCE (BUS_03) packet — 2-hop path: BUS_03 -> BUS_02 -> BUS_01 -> Ground.
  //         hop == EXPECTED_HOPS, relay chain must contain both RELAY_1 and RELAY_2.
  if (hop != FORCED_HOP_TEST_EXPECTED_HOPS) return false;

  // relay_chain (compact-decoded) is a proper JsonArray.
  // rc (raw vehicle packet) may be stored as a compact string ("B2,B1") since
  // the vehicle serialises it that way; handle both forms.
  bool foundRelay1 = false;
  bool foundRelay2 = false;

  if (compactPacket) {
    JsonArray chain = doc["relay_chain"].as<JsonArray>();
    if (chain.isNull()) return false;
    for (JsonVariant item : chain) {
      const char* id = item | "";
      if (strcmp(id, FORCED_HOP_TEST_RELAY_1) == 0) foundRelay1 = true;
      if (strcmp(id, FORCED_HOP_TEST_RELAY_2) == 0) foundRelay2 = true;
    }
  } else {
    // rc may be a JSON array (expanded doc) or a compact string.
    if (doc["rc"].is<JsonArray>()) {
      JsonArray chain = doc["rc"].as<JsonArray>();
      for (JsonVariant item : chain) {
        const char* id = item | "";
        if (strcmp(id, FORCED_HOP_TEST_RELAY_1) == 0) foundRelay1 = true;
        if (strcmp(id, FORCED_HOP_TEST_RELAY_2) == 0) foundRelay2 = true;
      }
    } else if (doc["rc"].is<const char*>()) {
      // Compact string format, e.g. "B2,B1" — expand each token.
      const char* rcStr = doc["rc"] | "";
      const char* start = rcStr;
      while (*start != '\0') {
        while (*start == ',' || *start == ' ') start++;
        const char* comma = strchr(start, ',');
        size_t len = comma ? (size_t)(comma - start) : strlen(start);
        char token[8] = "";
        size_t copyLen = len < sizeof(token) - 1 ? len : sizeof(token) - 1;
        memcpy(token, start, copyLen);
        token[copyLen] = '\0';
        String expanded = expandVehicleId(token);
        if (expanded == FORCED_HOP_TEST_RELAY_1) foundRelay1 = true;
        if (expanded == FORCED_HOP_TEST_RELAY_2) foundRelay2 = true;
        if (comma == nullptr) break;
        start = comma + 1;
      }
    }
  }

  return foundRelay1 && foundRelay2;
}

bool isValidThailandCoord(float lat, float lng);
int postBatchToServer(const String& body);
void bufferPacket(const char* payload, float rssi, float snr);
int bufferCount();
bool decodeCompactPacket(const String& raw, JsonDocument& out);
String buildServerPayload(JsonDocument& rx, float receivedRssi, float receivedSnr);

void forceWifiReconnect(const char* reason) {
  unsigned long now = millis();
  if (now - lastForcedWifiReconnectMs < 10000UL && lastForcedWifiReconnectMs != 0) return;
  lastForcedWifiReconnectMs = now;
  wifiConnected = false;
  Serial.printf("[WiFi] force reconnect reason:%s status:%d failures:%u\n",
                reason ? reason : "unknown", WiFi.status(), consecutiveHttpFailures);
  WiFi.disconnect();
  delay(100);
  WiFi.begin(WIFI_SSID, WIFI_PASS);
}

void beginLedPulse(unsigned long durationMs) {
  ledPulseActive = true;
  ledPulseUntilMs = millis() + durationMs;
  digitalWrite(LED_BUILTIN, LOW);
}

void serviceStatusLed() {
  if (ledPulseActive && (long)(millis() - ledPulseUntilMs) >= 0) {
    ledPulseActive = false;
    digitalWrite(LED_BUILTIN, HIGH);
  }
}

bool isCompactVehiclePacket(JsonDocument& doc) {
  return doc["id"].is<const char*>() && doc["pk"].is<const char*>() && doc.containsKey("ts");
}

String expandDirection(const char* code) {
  if (!code || code[0] == '\0') return "unknown";
  if (code[0] == 'I') return "inbound";
  if (code[0] == 'O') return "outbound";
  return "unknown";
}
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

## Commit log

2026-03-21 fix: offline timeout 30s + real sensor data
2026-05-13 fix: highway 4016 route NW, TWIN_01 routeId filter bypass in demo mode, map center update
2026-06-26 feat(ui): redesign frontend — compact design system, sidebar nav, modals, sparklines, admin layout
    - style.css: CSS variables (--card-padding, --sidebar-width, --nav-height), compact
    sizing (body 14px, headings 14-16px, stat numbers 24px), pill badges with dot,
    gradient navbar, colored metric-icon variants (blue/green/amber/purple),
    modal-overlay/panel for ประกาศ+ช่วยเหลือ, sparkline canvas util
    - shared.js: openAnnouncementModal() fetches /api/config announcement,
    openHelpModal() shows FAQ + contact panel, ensureModalsExist() lazy-injects
    both modals into body, drawSparkline() canvas utility, songthaewIllusSvg()
    geometric Thai red truck, new icon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
2026-06-26 Fix admin back button and demo mode issues
2026-06-27 feat: premium animated mesh graph - dot-grid BG, glowing links, flowing packets, gradient nodes, pill labels
2026-06-27 Stabilize offline vehicle heartbeats
    [Songthaew_V03_ground.ino, Songthaew_V03_vehicle.ino]
2026-06-27 Harden mesh relay links
2026-07-02 feat: add VIBE technology branding and explanation pages
    [solar_panel_box_parametric.scad]
2026-07-02 Add ground station config and fix demo return route
    [Songthaew_V03_ground.ino, Songthaew_V03_vehicle.ino, mesh_config.h]
2026-07-04 Fix telemetry backend and firmware memory handling
    [Songthaew_V03_vehicle.ino, mesh_config.h]
2026-07-05 Tune firmware stationary power handling
2026-07-05 Fix PDR live packet counting
    [Songthaew_V03_ground.ino, Songthaew_V03_vehicle.ino, mesh_config.h]
2026-07-06 Add LoRa config relay and command flow
2026-07-07 Fix public operations access and update firmware config
    [Songthaew_V03_ground.ino, Songthaew_V03_vehicle.ino, mesh_config.h]
2026-07-07 Stabilize LoRa diagnostics and online status
    [Songthaew_V03_ground.ino, Songthaew_V03_vehicle.ino, mesh_config.h]
2026-07-07 Fix telemetry upload and vehicle visibility
    [Songthaew_V03_ground.ino]
2026-07-10 Move battery calibration to server
2026-07-10 Show current battery readings in admin
2026-07-10 Link dashboard battery to calibration
2026-07-10 Queue ground telemetry and improve admin tabs
2026-07-11 Add admin ground station position controls
2026-07-13 Stabilize 3-vehicle firmware telemetry
    [Songthaew_V03_ground.ino, Songthaew_V03_vehicle.ino, mesh_config.h]
2026-07-15 Preserve relay chain in forced hop packets
2026-07-15 Keep ground listening through forced hop relay window
2026-07-15 Use deterministic relay delay for forced hop test
2026-07-15 Prioritize forced hop relay validation
2026-07-15 Preserve relay source in forced hop packets
2026-07-15 fix: forced-hop relay chain + connectivity table hop/relay display
    Vehicle firmware (Songthaew_V03_vehicle.ino):
    - buildLoRaPacket: include rc (relay chain) field in forced-hop packets
    so Ground can validate the full hop path on completion
    Ground firmware (Songthaew_V03_ground.ino):
    - isValidForcedHopCompletion: support both JSON Array and compact
    string (e.g. 'B2,B1') rc formats; check by presence of RELAY_1
    and RELAY_2 instead of strict size + order, making validation
    robust to both compact and expanded packet paths
    Dashboard (public/js/meshDashboard.js):
    - connectivityRows: show correct total hop count from node.hop
    instead of the first relay link's hop index
    - connectivityRow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
    [Songthaew_V03_ground.ino, Songthaew_V03_vehicle.ino]
2026-07-15 fix: mesh graph shows relay arrow for direct nodes (BUS_01)
    buildRealTelemetryLinks processed nodes in a single pass, so relay-chain
    links from BUS_03 (which includes a BUS_01 -> Ground 'relay' link) were
    sometimes registered before BUS_01's own direct link. The pair-key
    deduplication then blocked BUS_01's direct link from being added, causing
    the mesh graph to show BUS_01 with a red dashed relay arrow instead of a
    solid green direct arrow.
    Fix: add a Pass 1 that registers direct links (hop === 0) for all nodes
    before Pass 2 processes relay chains. This guarantees direct connections
    are never overwritten by relay-chain intermediate links.
2026-07-15 feat: extend forced-hop test to full 3-hop chain (BUS_03->BUS_02->BUS_01->Ground)
    Previously only BUS_03's packets were forced through the relay chain; BUS_02
    still transmitted its own telemetry directly to Ground (hop=0).
    Changes:
    - isForcedHopTestSource(): now returns true for both SOURCE (BUS_03) and
    RELAY_1 (BUS_02), so BUS_02 also sends its own packets via forced-hop.
    RELAY_2 (BUS_01) still transmits directly (it is the last relay).
    - forcedHopNextTargetFor(): extended to handle SOURCE -> RELAY_1 case in
    addition to RELAY_1 -> RELAY_2 and RELAY_2 -> Ground.
    - transmitPacket(): uses forcedHopNextTargetFor(VEHICLE_ID) to pick the
    correct target (BUS_02 targets BUS_01; BUS_03 ta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
    [Songthaew_V03_ground.ino, Songthaew_V03_vehicle.ino]
2026-07-15 fix: prevent watchdog reset in Ground Station firmware during HTTP POST
    The server response can take 3-5 seconds due to Firebase network latency
    in local development environments. This blocking call triggers the ESP8266
    software watchdog, causing the Ground Station board to reset (wdt reset).
    Fix: Disable the software watchdog timer right before calling http.POST() and
    re-enable/restore it with an 8-second timeout immediately after.
    [Songthaew_V03_ground.ino]
2026-07-15 fix: resolve stack memory corruption in compact vehicle packet decoder
    In decodeCompactVehiclePacket, stack-allocated char arrays (fullId, packetId,
    relayFrom, relayTo, expandedId) were assigned directly to JsonDocument keys.
    Because ArduinoJson saves char* by reference, this resulted in dangling stack
    pointers pointing to corrupted stack space after the function returned.
    This bug caused fields like relayFrom to evaluate to empty/garbage values,
    subsequently causing shouldRelay() on BUS_01 to incorrectly reject the
    relayed BUS_02 packets in forced-hop test mode.
    Fix: Explicitly cast these stack-allocated arrays to String objects to force
    ArduinoJson to copy the string data into its intern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
    [Songthaew_V03_vehicle.ino]
2026-07-15 fix: resolve potential dangling pointer issues in ground station compact decoder
    Ensures boot_id and packet_hash strings are cast to String before insertion
    into JsonDocument, mimicking the vehicle firmware memory safety fix.
    [Songthaew_V03_ground.ino]
2026-07-15 fix: resolve admin page map display crash and add ground station coordinates auto-save
2026-07-15 feat: switch ground station map on admin page to Google Maps Hybrid (satellite) view
2026-09-10 feat: optimize telemetry pipeline for 5s real-time updates and resolve 1-minute ground reconnect delay
    [Songthaew_V03_ground.ino, mesh_config.h]
2026-09-10 fix: simplify ground wifi connection and optimize render backend caching
    [Songthaew_V03_ground.ino, mesh_config.h]
2026-10-03 docs: replace cropped cutout device image with original full photo

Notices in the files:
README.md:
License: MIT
